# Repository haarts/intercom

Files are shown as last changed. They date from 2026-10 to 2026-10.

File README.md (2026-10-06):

# Intercom boerderij

A home intercom built from Waveshare ESP32-P4-WIFI6-POE-ETH wall boxes. There are two routes:

- **Mumble:** the boxes run a Mumble client. There is one Mumble server for the house,
  Mumble channels route audio to rooms, and Home Assistant is integrated.
- **lanicom** (`lanicom/`): serverless. Boxes find each other on the LAN and talk
  directly, with encrypted unicast. No Mumble server, and Home Assistant is optional (it can join as a
  peer), so friends can build it too. See [lanicom/README.md](lanicom/README.md) and the
  plan with its design review in [lanicom/PLAN.md](lanicom/PLAN.md).

| Path | What |
| --- | --- |
| `lanicom/` | Serverless intercom: protocol spec, C core, ESPHome component, Python CLI, HA integration |
| `esp32-mumble/` | [dchote/esp32-mumble](https://github.com/dchote/esp32-mumble) (git subtree) with ESP32-P4 support and audio fixes. Board config: `esp32-mumble/esphome/waveshare-esp32-p4-poe.yaml` |
| `esphome/p4-bringup.yaml` | Minimal bring-up config for the board (Ethernet, codec, mic level) |
| `server/mumble/` | Docker Compose file for the Mumble server (Murmur) |
| `tools/voicetest/` | End-to-end voice test: play speech near the board, record it from Mumble, score it with Whisper |
| `PROJECT_NOTES.md` | Decisions, measurements and open items |

## Build and flash

```sh
python3 -m venv .venv && .venv/bin/pip install esphome==2026.7.1
cd esp32-mumble/esphome
../../.venv/bin/esphome run waveshare-esp32-p4-poe.yaml   # first flash over USB-C, later OTA
```

The Mumble server address is filled in automatically with Home Assistant's IP when
the device is adopted, or set it under the device's "1. Server" setting.

## Voice test

```sh
tools/voicetest/run.sh local ptt tools/voicetest/berend-nl-pad.wav nl
```

Plays the clip on this machine's default audio output, records what the board sends
to the Mumble server, and prints Whisper's transcript and word error rate. See the
comments in `run.sh` for the options.

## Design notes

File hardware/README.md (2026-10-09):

# Intercom hardware

About ten wall boxes, each with a Waveshare ESP32-P4-ETH (sku ESP32-P4-POE-ETH, PoE module on top; no WiFi), a 40 × 40 mm speaker, four
illuminated push buttons (M19, Φ22 bezel, 3–6 V LED ring) and a 180 × 90 × 3 mm brass front
plate. The box sits on the in-wall box the UTP comes out of, with its back against the wall.

| Path | What | Status |
|---|---|---|
| `plate/front-plate-arches.dxf` | Front plate for the laser cutter | Holes corrected (below). Grille pattern still to check with the cutter. |
| `plate/front-plate-arches.scad` | The same plate for the enclosure model, generated by `plate/dxf2scad.py` | Regenerate after changing the DXF |
| `enclosure/intercom.scad` | Parametric OpenSCAD model of the 3D-printed prototype: shell, wall plate, mic tube | Carrier + ESP32-P4-ETH version, not printed yet |
| `carrier/` | KiCad project for the button/LED carrier board | Rev B in KiCad (adds the off switch J8): ERC clean, DRC 0 errors / 0 unconnected. `carrier/export/` still holds rev A, which is what was ordered. |

## GPIO map (P4-ETH header P1, Pico-style numbering)

Pin 1 is at the USB-C end of the left row, seen from the top with USB-C pointing up; pins 21–40 run back
up the right row, from the RJ45 end. Source: Waveshare's [ESP32-P4-ETH](https://docs.waveshare.com/ESP32-P4-ETH) pinout.

| Use | GPIO | P1 pin | Carrier socket |
|---|---|---|---|
| Button 1 (PTT) | GPIO23 | 31 | J7.11 |
| Button 2 | GPIO22 | 32 | J7.12 |
| Button 3 | GPIO21 | 34 | J7.14 |
| Button 4 | GPIO20 | 35 | J7.15 |
| LED ring 1 | GPIO5 | 11 | J1.11 |
| LED ring 2 | GPIO32 | 26 | J7.6 |
| LED ring 3 | GPIO4 | 12 | J1.12 |
| LED ring 4 | GPIO33 | 25 | J7.5 |
| Spare | GPIO2, GPIO3 | 15, 14 | J1.15, J1.14 → J6 |
| Off switch (`EN` = `3V3_EN`) | | 37 | J7.17 → J8 (rev B; a bodge on rev A, see below) |
| +5 V (VSYS) | | 39 | J7.19 |
| GND | | 3, 8, 13, 18, 23, 28, 33, 38 | |

## Carrier board (`carrier/`)

90 × 48 mm, two layers, through-hole only so it can be hand-soldered.

**The P4:**
- **Mounting:** it plugs in from above into two 1×20 female sockets (J1 = P1 pins 1–20, J7 = pins 21–40), 17.78 mm apart.
- **Orientation:** the silkscreen marks the RJ45 end and the USB-C end.
- **Under the P4:** only traces, so the P4's bottom-side parts are clear.
- **PoE module:** it stays on top of the P4 as usual; nothing on the carrier is near it.

**Per button** (four channels along the bottom edge, BTN1–BTN4 from left to right). The buttons are numbered in the order their GPIOs leave the header, so the four button lines run side by side without crossing:
- **Connector:** a JST-XH 4-pin. Pin 1 = LED+ (+5 V), 2 = LED−, 3 = switch, 4 = GND.
- **Switch input:** 1 kΩ in series to the GPIO, with 100 nF to GND. The pull-up is the ESP32's own; a pressed button reads low.
- **LED ring:**
  - switched low-side by a BC547, with a 1 kΩ base resistor and a 10 kΩ base pull-down that keeps it off during boot;
  - a series resistor (R13–R16) is fitted with 0 Ω until a ring's current at 5 V has been measured.

**Also on the board:**
- 10 µF on 5 V (C5).
- J6, a 1×4 header for the spares: GPIO2, GPIO3, GND, GND. It is at the USB-C end, so don't use it while a USB cable is plugged in.
- J8 (rev B), a JST-XH 2-pin for the off switch: 1 = `3V3_EN` (P1 pin 37), 2 = GND, with C6 (100 nF) across it.
  It is in the bottom-right corner, in line with the button JSTs; J5 moved 1 mm to the left to make room.
- GND pours on both layers.
- Four M3 holes (H1–H4).

ESPHome: buttons `INPUT_PULLUP`, `inverted: true`; LEDs as `ledc` outputs (dimming, pulsing).

### Off switch

Rev B has it on J8 (above). The notes below apply to both revisions; the wiring is the rev A bodge.

A toggle switch between J7.17 (P1 pin 37) and J7.18 (pin 38, GND) turns the box off. Closed = off.
Both socket pins are free on rev A and sit next to each other, so it is two wires on the carrier and nothing on the P4.

From Waveshare's [schematic](https://files.waveshare.com/wiki/ESP32-P4-ETH/ESP32-P4-ETH-datasheet.pdf):
- **What pin 37 is:** `EN` on the header is `3V3_EN`, the enable of the MP1658 buck (U1) that makes `ESP_3V3` from 5 V.
  It is pulled up to 5 V with 10 kΩ (R21). Pulling it low removes 3.3 V from the P4, so the switch is a real power-off,
  not a reset or sleep, and firmware can't override it.
- **Pin 30 is a different pin:** `RUN` is `ESP_EN` (the RESET button). Holding it low keeps the chip in reset with everything still powered.
- **What stays powered while off:**
  - the PoE module;
  - the analog 3.3 V LDO (U8, always enabled) for the codec and mic;
  - the power LED.
- **What goes dark by itself:**
  - the speaker amp (NS4150B, CTRL = GPIO53 with a 10 kΩ pull-down);
  - the LED rings (base pull-downs).
- **Wiring:** keep the wires inside the box and twisted. A 100 nF cap across the switch is cheap insurance against noise on EN.
- **Switching back on** is a cold boot. Partners see the box as offline after 30 s, because no `bye` is sent.
- **Factory reset still works:** ESPHome counts power-on resets, so flicking the switch 5 times within 10 s
  does a factory reset, like 5 power cycles. That is intended: the switch is a handy reset gesture.
- **To check on the first board:**
  - with the switch off, `ESP_3V3` (pin 36) should read ~0 V. If it floats at 1–2 V, something is back-powering the P4 through its IO pins;
  - measure the power draw while off.

## Front plate

`plate/front-plate-arches.dxf` is a copy of `intercom-grill-arches.dxf` (2026-09-30) with two fixes:

- **Button holes:** Ø16 → **Ø19.4**, for the M19 switches.
- **Mounting holes:** Ø3.0 → **Ø3.3**, for M3.

The countersink note (layer `INFO_CSK`, Ø6) is unchanged.

Still open:
- the grille's minimum slot and web width, to agree with the laser cutter;
- the switches' thread length and nut size;
- each bezel's top edge touches the bottom of the grille (y = 25 mm). Check that this looks right.

## Enclosure prototype (3D print)

```
enclosure/render.sh        # needs an OpenSCAD development snapshot (2025 or later): `openscad-nightly`,
                           # `openscad`, or OPENSCAD=/path/to/OpenSCAD.AppImage
```

The model is one file, `enclosure/intercom.scad`. Every dimension a test print may change is a
parameter at its top. Open it in OpenSCAD to look around: `part` selects what is shown
(`assembly`, `shell`, `wall_plate`, `mic_tube`, `section`).

It is designed in front-view coordinates (X right, Y up, Z into the wall), the way the plate
drawing and KiCad's top view read. Every output is mirrored once into the right-handed frame
that slicers use; without that, the print would be a mirror image of the box.

`render.sh` writes to `enclosure/out/`:
- `shell`, `wall_plate` and `mic_tube`, each as `.stl` and `.3mf` (the plate is brass, so it's never in them);
- preview PNGs: front, back, iso, inside, inside_iso and a section through the carrier;
- a collision check between the shell, the plate, the electronics, the speaker, the buttons
  and the mic tube, with the electronics, speaker and buttons as blocks. It fails if any two
  of them overlap (faces that merely touch are fine);
- how much of the mic tube's bore is covered by brass where it meets the plate (should be 0 %).

The plate in the model is the real one: OpenSCAD can't read the DXF's R12 polylines, so
`plate/dxf2scad.py` converts it (`python3 dxf2scad.py front-plate-arches.dxf > front-plate-arches.scad`).

**Shell, 185.4 × 95.4 × 52 mm:**
- **Plate:** sits in a rebate, flush with the front, and is screwed to four corner bosses with M3 heat-set inserts.
- **Inside, from the left:**
  - the speaker in a closed chamber, which improves the low end; a ledge holds it against the plate;
  - the cable opening, right next to the P4's RJ45 jack;
  - the carrier on four 5 mm standoffs (M3 inserts) on the back wall, above the buttons, components towards the plate.
- **The stack, from the back wall:**
  - carrier (component side at 42.4 mm behind the front);
  - 8.5 mm sockets;
  - the ESP32-P4-ETH (component side at 32.3 mm);
  - the RJ45 and the PoE module, which stick out about 13 mm towards the plate.

  That leaves about 16 mm free behind the plate.
- **Buttons:** the JSTs are on the carrier's bottom edge, a short cable away from them.
- **Bottom:** vent slots under the carrier. Warm air leaves through the grille.
- **USB-C:** it points at the right side wall with only 9 mm to spare. Flash the P4 before you mount it; after that, update it over the network (OTA).

**Wall plate, 174 × 85 × 3 mm:**
- **Mounting:** it screws onto the in-wall box.
  - Slots fit 60 mm screw spacing, horizontal or vertical, around `WALLBOX_CENTER` (behind the cable opening by default).
  - The shell's back has recesses for the screw heads.
- **Fixing the shell:** hang the shell on the two top hooks (above the carrier) and slide it 5 mm down. Two M3 screws from below go into the wall plate's tabs.

**Print settings:** PETG (or ASA near a heat source), 0.2 mm layers, 4 perimeters around the inserts.
Print the shell with its back on the bed; the rebate and bosses need no supports.

**Hardware per box:**
- 4× M3 heat-set inserts + M3×8 countersunk screws for the plate;
- 4× M3 inserts + M3×6 screws for the carrier;
- 2× M3 inserts + M3×16 screws to fix the shell to the wall plate;
- 2 screws for the wall box (usually supplied with it).

### To verify with the first print
- **Mic:** it is on the P4, next to the USB-C, 29 mm behind the plate (`MIC_XY` in the script), and will sound muffled without help.
  It is top-port (a hole in its lid, near the end towards the USB-C), so it hears towards the plate.
  - `mic_tube.stl` runs from the plate to 3.6 mm in front of the mic, clear of the USB-C. Glue its flange behind the plate and close the last gap with a foam ring.
  - It starts behind a grille opening (`MIC_GRILLE_XY`, the bore fully open) and slants about 7° to the mic.
  - Its 3 mm bore is centred on the lid's hole, whose position is estimated (~0.8 mm from the mic's
    USB-C end). Check it against the board before gluing; `MIC_XY` moves it.
- **PoE module:** modelled as a 32 × 26 × 13 mm block. Check the real height and overhang.
- **Cable:** the RJ45 plug and the cable's bend between the jack and the cable opening. A slim patch cable helps.
- **Speaker chamber:** the wires leave through a 4 × 3 mm notch where the chamber's right wall meets the back wall.
  Seal it with hot glue after fitting, check the chamber is airtight, and add foam between the speaker and the plate.
- **Button depth:** 46 mm inside depth assumes a 33 mm body plus its plug. Measure the real buttons.
- **Button cables:** the JSTs are labelled BTN1–BTN4 from left to right; cut each cable to its button.

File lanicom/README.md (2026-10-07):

# lanicom: serverless LAN intercom

Push-to-talk intercom devices that find each other on the LAN and talk
directly. No Mumble server, and Home Assistant is optional (it can join as a
peer). Every packet is encrypted and authenticated with a shared network key.

- Why it's built this way, the status and the latency budget: [PLAN.md](PLAN.md)
- The wire protocol: [spec/PROTOCOL.md](spec/PROTOCOL.md)
- Setting up devices (for friends): [docs/friends.md](docs/friends.md)
- Buttons, pairing and LED patterns: [docs/buttons.md](docs/buttons.md)

| Path | What |
|---|---|
| `spec/` | Protocol, protobuf schema, shared test vectors |
| `lanicom-core/` | Portable C protocol engine (used by the firmware), with host tests |
| `esphome/` | ESPHome component and the Waveshare ESP32-P4 board config |
| `python/` | Reference implementation and the `lanicom` command-line peer |
| `ha/` | Home Assistant integration |

## Try it on two computers

```sh
pip install -e 'lanicom/python[audio]'   # needs libopus0 and PortAudio (Debian: apt install libopus0 libportaudio2)
lanicom keygen --save                    # once; copy ~/.config/lanicom/key to the other machine
lanicom list                             # who is on the network
lanicom talk --to all                    # Enter starts/stops talking; also plays what others say
lanicom send doorbell.mp3 --to all       # play a file (needs ffmpeg)
lanicom record out.wav --duration 10     # record what others say
```

## Tests

```sh
cmake -S lanicom/lanicom-core -B lanicom/lanicom-core/build && cmake --build lanicom/lanicom-core/build \
  && ctest --test-dir lanicom/lanicom-core/build          # C core (needs libmbedtls-dev), ASan/UBSan
pip install -e 'lanicom/python[test]' && pytest lanicom/python   # Python + C interop (after the C build)
cd lanicom/ha && pytest                                   # HA (pip install pytest-homeassistant-custom-component ha-ffmpeg)
```

After changing the protocol, regenerate the vectors (`python lanicom/python/tools/gen_vectors.py`)
and the integration's copy of the library (`python lanicom/ha/sync_lib.py`).

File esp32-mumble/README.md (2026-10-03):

# ESP32-Mumble

An ESP32-S3 Mumble voice chat client for ESPHome, turning microcontroller boards into always-on intercoms and push-to-talk devices.

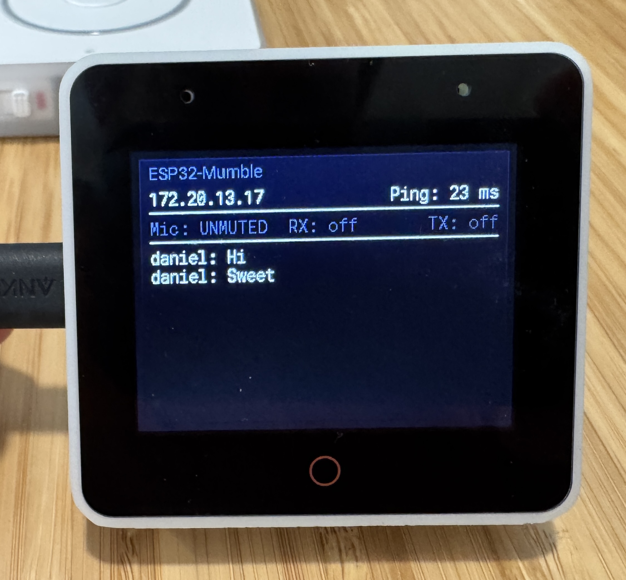
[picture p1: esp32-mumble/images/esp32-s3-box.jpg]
ESP32-S3-BOX running ESP32-Mumble


*The project running on an ESP32-S3-BOX connected to a local go-mumble-server instance.*

## What Is This?

ESP32-Mumble implements the [Mumble](https://www.mumble.info/) voice chat protocol on ESP32-S3 hardware. **Default crypto is Legacy** (OCB2-AES128, standard Mumble); **Lite** (cleartext UDP, minimal CPU) is optional for trusted LAN. Connects to [go-mumble-server](https://github.com/dchote/go-mumble-server) or Murmur.

The firmware runs as an [ESPHome](https://esphome.io/) external component, integrating with Home Assistant for configuration and control.

### Key Capabilities

- **Three operating modes**: Always-on intercom, push-to-talk, and **Communicator** (Star Trek-style half-duplex)
- **Crypto modes**: **Legacy** (default) — OCB2-AES128; **Lite** — cleartext UDP for trusted LAN; **Secure** — AES-256-GCM when server negotiates it (go-mumble-server)
- **Opus** audio encoding/decoding at 16 kHz
- **Microphone capture and transmit** (Opus encode, VAD, echo suppression)
- **Acoustic echo cancellation** for open-mic use
- **Home Assistant** entities for server config, mode, mute, volume, channel, and status
- **Multi-room** intercom via Mumble channels

---

### Communicator Mode

Communicator mode turns any supported board into a **Star Trek-style half-duplex intercom**. A single button press opens a communication session with an audible chime, transmits your voice, and automatically closes when you stop talking.

**How it works:**

1. **Press the button** — an open chime plays, then the microphone goes live
2. **Speak** — audio is transmitted via Mumble with VAD (voice activity detection); silence is not sent
3. **Stop speaking** — after 2 seconds of silence the session auto-closes with a close chime
4. **Press again during a session** — immediately cancels and plays the close chime

While a communicator session is active, incoming voice is suppressed so the bus stays on the microphone. The chime is embedded directly in the firmware as raw PCM and played through the component's own bus-aware speaker path — no media player needed.

Communicator mode is selectable from the **Mode** entity in Home Assistant (alongside Always On and Push to Talk) and persists across reboots. On boards with a physical button (Box, Box-3, Atom Echo, Voice PE), the same button handles all three modes automatically.

---

## Supported Hardware

| Board | Framework | Mic | Speaker | Highlights |
|---|---|---|---|---|
| ESP32-S3 Box | ESP-IDF | ES7210 mic array | ES8311 DAC | lwIP netconn UDP |
| ESP32-S3 Box 3 | ESP-IDF | ES7210 mic array | ES8311 DAC | Same as Box; pin differences |
| Home Assistant Voice PE | ESP-IDF | XMOS dual mic | AIC3204 DAC | Jog volume, mute slider, center PTT, LED ring |
| Onju Voice | Arduino | SPH0645 I2S | MAX98357A I2S | Nest Mini form factor, touch, LEDs |
| M5Stack Atom Echo | Arduino | PDM mic | External DAC | Compact |
| Generic ESP32-S3 | Arduino | Any I2S mic | Any I2S DAC/amp | User-defined pins |
| Waveshare ESP32-P4-WIFI6-POE-ETH | ESP-IDF | Analog mic via ES8311 | ES8311 DAC | ESP32-P4 (rev3), Ethernet/PoE, native esp-idf toolchain |

The ESP32-S3 boards require PSRAM and Wi-Fi. The ESP32-P4 board connects over Ethernet and
builds with ESPHome's native esp-idf toolchain (see `esphome/waveshare-esp32-p4-poe.yaml`).

## Architecture

```
ESP32-S3                              go-mumble-server
┌────────────────────┐               ┌──────────────────┐
│ ESPHome Component  │──TCP/TLS────►│  Control (64738)  │
│                    │               │                   │
│ Mic/Opus encode    │               │  Voice  (64738)   │
│ Opus Dec ► I2S Spk │◄──UDP voice (rx/tx)────│
│                    │               └──────────────────┘
│ HA Entities ◄─────►│ Home Assistant
└────────────────────┘
```

See the full documentation:

- **[Product Overview](docs/product-overview.md)** -- Vision, use cases, features, and target hardware
- **[Technical Overview](docs/technical-overview.md)** -- Protocol details, audio pipeline, ESPHome integration, and hardware abstraction

## Prerequisites

- A Mumble server (e.g. [go-mumble-server](https://github.com/dchote/go-mumble-server) or Murmur) on your LAN
- [ESPHome](https://esphome.io/) 2026.7.0+ (pin via `pip install -r requirements.txt` → 2026.7.1)
- Python 3.12+
- [Home Assistant](https://www.home-assistant.io/) (optional, for configuration and control UI)
- One of the supported ESP32-S3 boards listed above

## Quick Start

```bash
# Clone, set Wi‑Fi in esphome/secrets.yaml; server defaults to empty and is auto-filled from HA when adopted
esphome compile esphome/esp32-s3-box.yaml   # Box: ESP-IDF; or generic-esp32s3.yaml for Arduino
esphome run esphome/esp32-s3-box.yaml --device /dev/ttyUSB0
```

For Box/Box-3 (ESP-IDF): first flash must be via USB, not OTA.

See [docs/build.md](docs/build.md) for full build and flash instructions.

## OTA Updates & Releases

Pre-built firmware is published from SemVer tags (`vX.Y.Z`) via GitHub Actions:

| Channel | URL |
|---|-----|
| Web installer (USB / ESP Web Tools) | https://dchote.github.io/esp32-mumble/ |
| Per-board OTA manifests | `https://dchote.github.io/esp32-mumble/<board>/manifest.json` |
| GitHub Release assets | https://github.com/dchote/esp32-mumble/releases |

Board slugs: `esp32-s3-box`, `esp32-s3-box3`, `home-assistant-voice-pe`, `m5stack-atom-echo`, `generic-esp32s3`.

After a device is adopted in Home Assistant, the **Firmware Update** entity checks the board's GitHub Pages manifest (every 6 hours) and can install OTA updates. Manifests and `.ota.bin` files are hosted on Pages (not `releases/latest/download`) to avoid GitHub redirect URL length limits on the device HTTP client.

**One-time maintainer setup:** enable GitHub Pages for this repo with **Source = GitHub Actions** (Settings → Pages). See [docs/features/0015-ota-releases.md](docs/features/0015-ota-releases.md).

**Cut a release:**

```bash
git tag v1.0.0
git push origin v1.0.0
```

Configure Mumble server, port, username, password, channel, mode, and crypto from the Home Assistant UI after adding the device. **Server** defaults to empty and is auto-populated with the Home Assistant server IP when the device is adopted by HA (e.g. for the go-mumble-server addon); set it manually in YAML or HA to override. **Crypto** defaults to Legacy (OCB2-AES128). Values persist in NVS and are restored on boot. Username defaults to `esp32-<MAC>`; you can overwrite it. Changing server, username, password, channel, or crypto forces a reconnect. **Mode** selects between Always On, Push to Talk, and Communicator — switching modes takes effect immediately (mic is disabled when leaving always-on). Use **Speaker Volume** to adjust playback level. On Box/Box-3, **Speaker Power** controls the hardware amplifier. Diagnostics show connection status, ping, and voice activity. The **Reset Config** button restores all settings to defaults (server to empty, re-triggering HA auto-detection). See `esphome/generic-esp32s3.yaml` for the full pattern.

## Project Structure

```
esp32-mumble/
├── components/          # ESPHome external components
│   └── mumble/          # Mumble client component
├── lib/
│   └── micro-opus/      # Local Opus codec (v0.4.1; heap pseudostack, PSRAM, Xtensa)
├── scripts/
│   ├── build.sh
│   ├── flash.sh
│   ├── generate_communicator_chime.py
│   └── patch_mbedtls_requires.py
├── docs/
│   ├── build.md
│   ├── features/        # Including 0015-ota-releases.md
│   ├── product-overview.md
│   └── technical-overview.md
├── esphome/             # Example device configs + secrets.example.yaml
├── .github/workflows/   # build.yml (PR/main) + release.yml (tags → Pages/Releases)
├── requirements.txt     # Pins esphome==2026.7.1
├── SECURITY.md
├── README.md
└── LICENSE
```

Install the host toolchain with `pip install -r requirements.txt`. See [docs/build.md](docs/build.md) and [SECURITY.md](SECURITY.md).

## Contributing

This project is in early development. Contributions, ideas, and hardware testing are welcome. Please open an issue to discuss before submitting large changes. Run `pre-commit run --all-files` before opening a PR.

## License

[MIT](LICENSE)

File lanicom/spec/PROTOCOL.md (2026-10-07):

# lanicom protocol, version 1

Normative. The key words MUST, SHOULD and MAY are as in RFC 2119. Test vectors
are in [`vectors/`](vectors/); every implementation MUST pass them.

lanicom is a serverless push-to-talk intercom for one LAN. Every device is an
equal peer. Devices find each other with authenticated broadcast `Hello`
messages and send audio directly to each other over UDP.

## 1. Transport

- All traffic uses UDP port **47100** (configurable; every device in a network
  MUST use the same port). One socket sends and receives both packet types.
- Discovery uses the IPv4 limited broadcast address `255.255.255.255`.
- Optional multicast (section 8) uses group `239.255.76.73` on the same port.
- A packet MUST NOT exceed 1200 bytes. Receivers drop larger datagrams.
- IPv6 is out of scope for v1.

## 2. Keys

Every device in a network shares one **key string**, normally generated by
`lanicom keygen` (25 random base32 characters in five dash-separated groups,
125 bits). Any passphrase works, but a weak one can be brute-forced offline
from one captured packet, despite the PBKDF2 stretching.

Leading and trailing whitespace is stripped. Everything else, including case and
dashes, is significant.

```
master   = PBKDF2-HMAC-SHA256(password = UTF-8(key string),
                              salt = "lanicom-v1", iterations = 100000, dkLen = 32)
prk      = HKDF-Extract-SHA256(salt = "lanicom-v1", ikm = master)
key_id   = uint16_be(HKDF-Expand-SHA256(prk, info = "key-id", L = 2))
send_key(sender_id) = HKDF-Expand-SHA256(prk, info = "packet" || uint32_be(sender_id), L = 32)
```

- `key_id` is public. Receivers use it to drop traffic from other networks
  cheaply before attempting decryption. It also allows a future key rotation in
  which two keys are accepted at once.
- Each sender has its own AEAD key. Two devices that happen to pick the same
  epoch therefore never reuse a (key, nonce) pair.

## 3. Packet format

All integers are big-endian.

| Offset | Size | Field | Notes |
|---|---|---|---|
| 0 | 1 | `version` | `1` |
| 1 | 1 | `type` | `1` = CONTROL, `2` = AUDIO |
| 2 | 2 | `key_id` | from section 2 |
| 4 | 4 | `sender_id` | random at first boot, then persisted; never `0` |
| 8 | 8 | `epoch` | unique per sender per boot (see below) |
| 16 | 4 | `seq` | per sender, +1 for every packet sealed in this epoch, starts at 0 |
| 20 | n | ciphertext | |
| 20+n | 16 | Poly1305 tag | |

Packets are sealed with ChaCha20-Poly1305 (RFC 8439), using:

- `key` = `send_key(sender_id)`;
- `nonce` = bytes 8..19 of the header (`epoch || seq`, 12 bytes);
- `aad` = the 20-byte header.

The (key, nonce) pair MUST never repeat, which leads to these rules:

- `seq` is a single counter per sender. It is shared by both packet types and
  by all destinations.
- When a sender sends the same packet to several peers, it seals it **once** and
  sends identical bytes to each peer. This is allowed and is cheaper.
- `epoch` MUST NOT repeat for a given sender. RECOMMENDED: `uint32 boot_counter`
  (persisted and incremented before the first packet of a boot) `||` `uint32
  random`. Hosts without persistent storage use 64 random bits. Before `seq`
  would wrap, the sender MUST pick a new epoch.

### Receive procedure

A receiver processes each datagram in this order, stopping at the first
failing step. Every drop is counted per reason, and none produces a reply
except where noted:

1. The length is at least 36 and at most 1200, `version == 1`, and
   `type` is known. Otherwise drop (`malformed`).
2. `key_id` equals ours. Otherwise drop (`foreign`).
3. `sender_id` is not our own. If it is and `epoch` equals ours, this is our
   own broadcast looping back: drop it silently. If it is with a different
   epoch, another device has the same id: drop it, and if the packet also
   authenticates, pick a new random `sender_id`.
4. Open with `send_key(sender_id)`. If this fails, drop (`auth`).
5. Epoch verification (section 4). Packets from an unverified epoch are only
   used as described there.
6. Replay check against the sender's verified epoch (section 4). Duplicates
   and too-old packets are dropped (`replay`).
7. Update the peer's address (source IP and port) and `last_seen`, then
   dispatch on `type`.

## 4. Epoch verification and replay protection

An attacker on the LAN can record packets and send them again later. A
per-epoch sliding window (64 packets) catches replays within one epoch.
Without further checks, though, a receiver that never saw an epoch, or that
rebooted since, would accept a whole recorded session. Epoch verification
closes that gap with a challenge that needs no clock:

- Each peer entry has a `verified_epoch` (initially none).
- When an authenticated packet arrives from an epoch other than
  `verified_epoch`, the receiver does this:
  - **Hello with `echo` equal to the challenge pending for that peer:** set
    `verified_epoch` to the packet's epoch, start a fresh replay window at its
    `seq`, clear the challenge, and process the Hello normally.
  - **Anything else:** send that peer (at the packet's source address) a
    unicast Hello with a fresh random non-zero 64-bit `challenge`, at most once
    per 250 ms per peer. Create the peer entry if it is new. Then drop the
    packet, except that a Hello's own `challenge` field (if any) is still
    answered, as below. Nothing else changes.
- A Hello carrying `challenge = c` is always answered with a unicast Hello
  whose `echo = c`, sent from the current epoch, even if the challenger is not
  verified yet. Replies are limited to 10 per second per source address.
- The replay window keeps the highest `seq` seen and a 64-bit bitmap of the
  64 `seq` values below it. A packet more than 63 behind the highest is
  dropped as too old. A packet whose bit is already set is dropped as a
  duplicate.

Two peers meeting for the first time thus verify each other within two round
trips, in practice when the first `Hello` is seen and long before anyone
talks. A rebooted sender's first audio frames arrive before peers have
verified its new epoch only if it talks within about 1 ms of booting.

**Residual risks (accepted for v1):**
- Every holder of the network key can impersonate any `sender_id`. There are no
  per-device identities; this is a non-goal.
- `key_id`, sender ids, epochs, packet sizes and timing are visible, so traffic
  analysis can tell who is talking to whom.

## 5. Control messages

The CONTROL plaintext is one protobuf `Control` message, as defined in
[`lanicom.proto`](lanicom.proto). Unknown fields MUST be skipped.

### Discovery and liveness

- A device sends a `Hello` (with no `challenge` or `echo`) to the broadcast
  address at start-up, three times (at 0, 0.5 and 1.5 s). After that it sends
  one every 5 s, with ±1 s random jitter.
- It also sends `Hello` to any statically configured peer addresses on the same
  schedule. This is for networks where broadcast doesn't reach, such as across
  routed VLANs.
- A peer is forgotten after 30 s without a verified packet, or immediately on
  a verified `Hello` with `bye = true`.
- `name` is a display name (UTF-8, ≤ 32 bytes). A changed name takes effect
  with the next `Hello`.
- `caps`: bit 0 `PLAYBACK` (plays audio), bit 1 `CAPTURE` (can talk), bit 2 `MONITOR`
  (wants talk metadata for every stream, e.g. Home Assistant, without receiving audio),
  bit 3 `ANNOUNCER` (v1.1: may talk to any device, see section 7).
- `links` (v1.1): the sender's linked buttons, see section 7.

### Talk metadata

- `TalkStart {target, stream_id}` is sent just before each of a stream's first
  three audio packets, and `TalkStop {stream_id}` three times after its last
  one. Both go by unicast to every recipient of the stream and to every
  verified peer with `MONITOR` set, whatever the target. They are never sent
  by multicast.
- These are **informational** (for UI, LEDs and Home Assistant events). Playback
  MUST NOT depend on them: a stream starts with its first audio packet and ends
  after 300 ms without audio, or on `TalkStop`.
- Receivers dedupe both on (sender_id, stream_id).

## 6. Audio

The AUDIO plaintext is:

| Offset | Size | Field |
|---|---|---|
| 0 | 4 | `stream_id`, random per talk spurt (never 0) |
| 4 | 4 | `ts`: timestamp of the first sample, in 48 kHz ticks, random start, +480 per 10 ms |
| 8 | n | exactly one Opus packet (n ≥ 1) |

- **Codec:** Opus, mono. Senders SHOULD encode at 16 kHz in VOIP mode with
  in-band FEC enabled, 10 ms frames (20 ms is allowed, for example to halve the
  packet rate on Wi-Fi), at 16 to 24 kbit/s.
- Receivers MUST accept 10, 20, 40 and 60 ms frames. They get the frame length
  from the Opus packet itself.
- The jitter buffer orders frames by `ts`. It MUST NOT use the header `seq`:
  that counter also advances for packets sent to other peers, so gaps in it say
  nothing about loss.
- On a missing frame, the receiver decodes the next frame's in-band FEC if that
  frame is already buffered, and uses Opus PLC otherwise.
- Concurrent streams are mixed (summed with saturation). There is no floor
  control.

### Addressing

A talker resolves its `Target` against its peer table at send time:

- `device`: that peer.
- `all`: every peer.

To reach a set of devices, a talker sends one stream to all of them, and each of
them gets its own `TalkStart` naming it (`device`). Devices can join or leave a
running stream: a joining device gets its three `TalkStart`s, a leaving one its
three `TalkStop`s.

A talker only includes peers that have `PLAYBACK` set and are verified. It seals
each frame once and sends a copy to every peer in the set (unicast fan-out).

## 7. Buttons and pairing (v1.1)

Devices with buttons (wall boxes) talk only through their buttons. Each button
is **linked** to exactly one button on another device, its partner. Holding a
button talks to its partner; holding several talks to all their partners in one
stream (section 6, Addressing). Buttons are numbered from 1.

### Pairing

1. Holding an unlinked button for 5 s puts it in **pairing mode** for 60 s. A
   linked button never enters pairing mode (a long hold is a long talk). A short
   press ends pairing mode.
2. In pairing mode the device broadcasts `PairOffer {nonce, button}` once a
   second. `nonce` is random, non-zero, new for each pairing mode.
3. Every device remembers the offers it hears (sender, nonce, button) until
   none has arrived for 2.5 s.
4. When a button enters pairing mode and an offer is known that none of the
   device's own buttons is already answering, it answers the oldest one (first
   heard) instead of offering: `PairAccept {nonce, button}` by unicast to the
   offerer, `button` being its own. It repeats the Accept every 500 ms until it
   gets a `PairConfirm`, for up to 5 s; then it forgets that offer and offers
   itself.
5. If two buttons offer at the same time, the one with the larger nonce accepts
   the other's offer (unsigned comparison), so exactly one side accepts.
6. The offerer, on a `PairAccept` whose nonce matches a button in pairing mode
   that isn't itself accepting, sends `PairConfirm {nonce}` by unicast and saves
   the link (its button, the sender, the sender's button). A repeated Accept for
   a link it already made with that nonce gets another Confirm, nothing else.
7. The accepter saves the link when the matching Confirm arrives.

Pairing messages are ordinary CONTROL traffic, so only holders of the network
key take part. The 5 s holds on both devices are the user's confirmation.

### Links heal themselves

Every `Hello` lists the sender's links (`Hello.links`). When a device hears a
verified `Hello` from a partner, it checks each of its links to that partner
that is older than 15 s. If the Hello doesn't list the reverse link (the
partner's button, our sender_id, our button), the partner has dropped it, and
the device drops its side too. Unpairing or resetting a device thus clears its
partners' buttons with its next Hello; a partner that was offline catches up
when both are back. There is no unlink message.

A device announces a change of links at once, with a broadcast `Hello`.

### Who plays what

A device with buttons plays audio only from its buttons' partners and from
peers with `ANNOUNCER` set (Home Assistant). It drops other streams. Anyone with
the network key can claim `ANNOUNCER`.

Devices that predate v1.1 skip the new fields and messages, and a device
without buttons plays everything, as in v1.

## 8. Multicast (optional)

A device MAY enable multicast. It then joins `239.255.76.73` and sends frames
for target `all` to the group once, instead of fanning out. Devices that don't
enable multicast never receive multicast audio. A network should therefore
either enable it on every device or on none.

Multicast is meant for wired-only installs. On Wi-Fi, multicast is sent at the
lowest basic rate without retries, and many access points drop or rate-limit
it, so stay with unicast there.

## 9. Constants

| Name | Value |
|---|---|
| port | 47100 |
| multicast group | 239.255.76.73 |
| max packet | 1200 bytes |
| PBKDF2 iterations | 100000 |
| Hello interval | 5 s ± 1 s |
| peer timeout | 30 s |
| challenge rate limit | 1 / 250 ms / peer |
| echo rate limit | 10 / s / source |
| replay window | 64 |
| stream timeout | 300 ms |
| pairing hold | 5 s |
| pairing mode | 60 s |
| PairOffer interval | 1 s |
| offer forgotten after | 2.5 s |
| PairAccept retry | every 500 ms, for 5 s |
| link grace (no heal check) | 15 s |

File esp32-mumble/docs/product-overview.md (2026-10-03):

# Product Overview

## Vision

ESP32-Mumble is an always-on intercom and push-to-talk voice client that runs on ESP32-S3 microcontrollers. It implements the Mumble voice chat protocol, connects to [go-mumble-server](https://github.com/dchote/go-mumble-server), and integrates with Home Assistant through ESPHome.

The project targets LAN deployments. **Legacy mode** (OCB2-AES128 UDP encryption, standard Mumble protocol) is the default and works with any Mumble server (Murmur, go-mumble-server). **Lite mode** (cleartext UDP) is available for trusted LAN use when the server supports it.

## Use Cases

### Always-On Intercom

The device listens and transmits continuously, acting as a room intercom. Audio from the microphone streams to the Mumble channel in real time. A physical mute button (or HA-controlled software mute) silences the microphone without disconnecting. This is the default operating mode.

### Microphone Control

Transmitting is controlled by a physical button wired to `mumble.microphone_enable` / `mumble.microphone_disable` (press = on, release = off). In push-to-talk mode this provides hold-to-talk; in always-on mode it toggles. On Box/Box-3, the touch-screen red circle below the display acts as the PTT button. The `mumble.ptt_press` action toggles mic state for single-press buttons.

### Star Trek Communicator Mode

In **communicator** mode, a single button press opens a half-duplex session:

1. An **open chime** plays through the speaker (bus-aware, embedded PCM)
2. The microphone goes live — VAD detects speech and transmits via Opus
3. When you stop talking, a **2-second silence window** starts; if you resume speaking, the timer resets
4. After 2 seconds of continuous silence the session auto-closes with a **close chime**
5. Pressing the button again during an active session **cancels immediately** and plays the close chime

Incoming voice is suppressed while a communicator session is active so the I2S bus stays on the microphone. The chime audio is embedded in the firmware as raw 16-bit PCM (generated from `esphome/sounds/communicator.wav` by `scripts/generate_communicator_chime.py`) and played through the component's own speaker path — no ESPHome media player needed.

The state machine has five states: `IDLE` → `OPEN_CHIME` → `MIC_ACTIVE` → `SILENCE_WINDOW` → `CLOSE_CHIME` → `IDLE`. Mode switching from Home Assistant takes effect immediately and cancels any active session.

### Multi-Room Intercom

Multiple ESP32-Mumble devices join the same Mumble server, each in an assigned channel or all in one shared channel. Rooms can be grouped or isolated by channel, with channel assignment configurable from Home Assistant.

### Home Assistant Integration

Each device appears in Home Assistant as an ESPHome node with configurable entities for server connection, operating mode (always-on / push-to-talk), mute state, volume, active channel, and talking status. Automations can mute devices on a schedule, switch channels in response to events, or trigger notifications when someone begins talking.

## Target Hardware

| Board | Framework | Microphone | Speaker/DAC | Notes |
|---|---|---|---|---|
| **ESP32-S3 Box 3** | ESP-IDF | ES7210 4-ch mic array | ES8311 DAC | lwIP netconn UDP; I2C codec control |
| **ESP32-S3 Box** | ESP-IDF | ES7210 4-ch mic array | ES8311 DAC | Older revision of Box 3 |
| **Home Assistant Voice PE** | ESP-IDF | XMOS dual-mic DSP | AIC3204 DAC | Jog wheel volume, mute slider, center PTT/Communicator, LED ring |
| **Onju Voice** | Arduino | SPH0645 I2S mic | MAX98357A I2S amp | Drop-in Google Nest Mini replacement; touch, LEDs, mute switch |
| **M5Stack Atom Echo** | Arduino | PDM microphone | External I2S DAC | Compact form factor |
| **Generic ESP32-S3** | Arduino | Any I2S microphone | Any I2S amplifier/DAC | User-defined pin configuration |

All targets require an ESP32-S3 with PSRAM and Wi-Fi. The S3's dual-core architecture is needed for simultaneous audio encode/decode and network I/O.

## Features

### Audio

- Opus decoding of received voice streams to speaker output — **implemented**
- Opus encoding of microphone input (16 kHz, mono, ~16 kbps) — **implemented**
- Half-duplex capture and playback (shared I2S bus; mic and speaker take turns)
- Echo suppression: transmit is suppressed while receiving or within 100 ms after
- Microphone array support with beamforming on boards with multi-channel ADCs (ES7210)

### Mumble Protocol

- **Legacy mode** (default): Standard Mumble protocol with OCB2-AES128 UDP encryption. Connects to Murmur, go-mumble-server, or any Mumble server.
- **Lite mode** (optional): Cleartext UDP voice, TLS control. Minimal CPU; use on trusted LAN when the server supports it (e.g. go-mumble-server with Lite enabled).
- Join a configured channel on connect
- Receive and transmit Opus voice packets (UDP when active; TCP tunnel fallback when UDP unreachable)
- Channel changes via `UserState` (e.g. from HA channel select)
- Respond to server pings to maintain connection
- UDP voice with TCP fallback (UDPTunnel) if UDP is unreachable

### Controls and Indicators

- Microphone on/off via physical button (`mumble.microphone_enable` / `mumble.microphone_disable`)
- Push-to-talk via physical button (press-and-hold)
- Volume control via touch surface, button, or Home Assistant
- LED status indication:
  - Connecting (slow pulse)
  - Connected/idle (steady)
  - Talking (active animation)
  - Muted (distinct color)
  - Error (red)

### Home Assistant Configuration

The following settings are exposed as Home Assistant entities and can be changed from the HA UI without reflashing the device. Values persist in NVS across reboots.

| Entity | Type | Description |
|---|---|---|
| Server | Text | Hostname or IP of the Mumble server. Defaults to empty; when the device is adopted by Home Assistant, it is auto-populated with the HA server IP (e.g. for go-mumble-server addon). Set manually to override. |
| Port | Text | Server port (default 64738, displays as integer) |
| Username | Text | Mumble username; defaults to `esp32-<MAC>` on first run (user can overwrite) |
| Password | Text | Server or user password; no default |
| Channel | Text | Channel to join on connect (default **Root**; case-insensitive match) |
| Mode | Select | **Always on**, **Push to talk**, or **Communicator** (persisted across reboots) |
| Crypto | Select | **Legacy** (OCB2-AES128, default) or **Lite** (cleartext UDP for trusted LAN) |
| Speaker Volume | Number | Playback volume level (0–100, default 80) |
| Speaker Power | Switch | Hardware amplifier power on/off (Box/Box-3 GPIO46; Voice PE GPIO47) |

All settings persist in NVS and are restored on boot — including speaker volume. Changing server, port, username, password, channel, or crypto forces an immediate reconnect.

### Home Assistant Diagnostics

| Entity | Type | Description |
|---|---|---|
| WiFi Signal | Sensor | WiFi RSSI in dBm |
| Mumble Connected | Binary Sensor | Whether connected to the Mumble server |
| Mumble Ping | Sensor | Round-trip ping time to server in ms |
| Voice Received | Binary Sensor | True while voice is being received and processed (Sensors) |
| Reset Config | Button | Restore server (to empty, re-triggering HA auto-detection), port, username, password, channel, mode, and crypto to defaults |

### Home Assistant Runtime Entities

| Entity | Type | Status | Description |
|---|---|---|---|
| Voice Sending | Binary Sensor | Implemented | True while the device is transmitting audio |
| Speaker Volume | Number | Implemented | Speaker volume level 0–100 (persists across reboots) |
| Speaker Power | Switch | Implemented | Hardware amplifier on/off (Box/Box-3, Voice PE; persists) |
| Mumble Connected | Binary Sensor | Implemented | Connection status (Diagnostics) |
| Voice Received | Binary Sensor | Implemented | True while receiving voice (Sensors) |
| Channel | Text | Implemented | Channel name to join (config) |
| Channel Select | Select | Optional | Server-populated channel list (`channel_select_id`) |

## Server Requirements

The client uses **Legacy** crypto by default; **Lite** is optional for trusted LAN.

**Legacy mode** (default):

- Any Mumble server (Murmur, go-mumble-server, etc.)
- Standard Mumble protocol with OCB2-AES128
- Opus codec enabled

**Lite mode** (optional):

- **go-mumble-server** or compatible with Lite crypto mode enabled
- Trusted LAN deployment
- TLS certificate (self-signed acceptable)

## Non-Goals (v1)

The following are explicitly out of scope for the initial version:

- Server administration from the device
- Client certificate / client-initiated Secure tier (server can negotiate Secure; client accepts it)
- CELT or Speex codec support
- Positional audio
- Multiple simultaneous server connections
- Audio recording or playback of stored media

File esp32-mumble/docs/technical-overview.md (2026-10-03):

# Technical Overview

## System Architecture

```
┌─────────────────────────────────────────────────────────────────────┐
│                        Trusted LAN                                  │
│                                                                     │
│  ┌──────────────────┐         ┌──────────────────────────────────┐  │
│  │  go-mumble-server│         │  ESP32-S3 Device                 │  │
│  │                  │◄───────►│                                  │  │
│  │  TCP/TLS :64738  │ Control │  ┌────────────┐  ┌───────────┐  │  │
│  │  (Version, Auth, │ Channel │  │ MumbleClient│  │ AudioPipe │  │  │
│  │   CryptSetup,    │         │  │ (TCP/TLS)  │  │ (I2S+Opus)│  │  │
│  │   Ping, Sync)    │         │  └─────┬──────┘  └─────┬─────┘  │  │
│  │                  │         │        │               │         │  │
│  │  UDP :64738      │◄───────►│  ┌─────┴───────────────┴─────┐  │  │
│  │  (Opus voice,    │  Voice  │  │  UDP Voice (Lite or Legacy) │  │  │
│  │   Lite/Legacy)   │  Packets│  │  Cleartext or OCB2-AES128   │  │  │
│  │                  │         │  └────────────────────────────┘  │  │
│  └──────────────────┘         │                                  │  │
│                               │  ┌─────────┐  ┌──────────────┐  │  │
│  ┌──────────────────┐         │  │ ESPHome │  │ Home         │  │  │
│  │  Home Assistant  │◄───────►│  │ API     │  │ Assistant    │  │  │
│  │                  │  Native │  │         │  │ Entities     │  │  │
│  │  Dashboard       │  API    │  └─────────┘  └──────────────┘  │  │
│  └──────────────────┘         └──────────────────────────────────┘  │
└─────────────────────────────────────────────────────────────────────┘
```

The ESP32-S3 device maintains two network connections:

1. **Mumble server** — TCP/TLS for control messages and UDP for voice packets (Lite: cleartext; Legacy: OCB2-AES128), both on port 64738. UDP voice works on Box/Box-3 (ESP-IDF netconn); TCP tunnel fallback when UDP unreachable.
2. **Home Assistant** -- ESPHome native API for entity state, configuration, and OTA updates.

## Mumble Protocol

### Connection Lifecycle

The server sends Version immediately after TLS handshake; the client responds with Version and Authenticate. CryptSetup is sent by the server *after* authentication as part of sync:

```
ESP32                                         go-mumble-server
  │                                                 │
  │──── TCP connect + TLS handshake ───────────────►│
  │                                                 │
  │◄─── Version (CryptoModes=0x07) ─────────────────│  Server sends first
  │──── Version (CryptoModes=0x01 or 0x02) ────────►│  Lite only or Legacy only (per user selection)
  │──── Authenticate (user, pass, opus=true) ──────►│
  │                                                 │
  │◄─── CryptSetup (key=empty or 16 bytes) ─────────│  After auth, signals mode
  │◄─── ChannelState[] ────────────────────────────│
  │◄─── UserState[] ──────────────────────────────│
  │◄─── ServerConfig ─────────────────────────────│
  │◄─── CodecVersion (opus=true) ──────────────────│
  │◄─── ServerSync (session, welcome) ─────────────│
  │                                                 │
  │──── UDP Ping ──────────────────────────────────►│
  │◄─── UDP Ping echo ────────────────────────────│
  │                                                 │
  │◄──► UDP Voice (Opus, Lite or Legacy) ◄────────►│
  │◄──► TCP Ping (keepalive) ◄────────────────────►│
```

**Channel selection** — The client joins the channel specified in the Channel text entity. Changing the channel in HA forces a reconnect; the new channel name is matched case-insensitively (e.g. `root` matches `Root`).

### Crypto Modes

go-mumble-server negotiates security per client during the Version exchange. The ESP32 client advertises supported modes; the server selects the best mutual tier. **Default crypto mode is Legacy** (OCB2-AES128).

| Mode | CryptoModes bit | UDP treatment | Use case |
|---|---|---|---|
| **Legacy** | 0x02 | OCB2-AES128, 4-byte overhead | Standard Mumble (Murmur, go-mumble-server); **default** |
| **Lite** | 0x01 | Cleartext, no per-packet crypto | Trusted LAN, minimal CPU; **optional** |
| **Secure** | 0x04 | AES-256-GCM, 28-byte overhead | go-mumble-server Secure tier (TLS 1.3 + client cert required) |

**Lite mode** — Client sends `CryptoModes = 0x01`. Server responds with CryptSetup (empty key). UDP voice is cleartext; TCP control remains TLS-encrypted. Suitable for trusted LAN deployments.

**Legacy mode (standard Mumble)** — Client sends `CryptoModes = 0x02` or `0x03` (Lite \| Legacy). Server responds with CryptSetup (16-byte key + 16-byte nonces). UDP voice is encrypted with OCB2-AES128. Compatible with any standard Mumble server. Legacy is the default. Changing crypto in HA (Legacy ↔ Lite) forces a reconnect so the server negotiates the new mode.

**Secure mode** — Server sends CryptSetup with 32-byte key and 12-byte nonces. UDP voice uses AES-256-GCM (packet format: 12-byte nonce \|\| ciphertext \|\| 16-byte tag). go-mumble-server only negotiates Secure when the client advertises 0x04 and uses TLS 1.3 with a client certificate. This client accepts Secure CryptSetup when the server chooses it; use of Secure tier from the client (advertising 0x04) requires TLS 1.3 and client cert support (not yet implemented).

**CryptSetup** — Key length indicates mode: 0 = Lite, 16 = Legacy, 32 = Secure. Legacy nonce resync: client may send CryptSetup with only `client_nonce`; server replies with `server_nonce`. The client triggers proactive resync before the Legacy nonce wraps (~256 packets).

**OCB2 implementation** — The Legacy OCB2-AES128 codec (`mumble_ocb2.cpp`) is ported from [mumble-voip/grumble](https://github.com/mumble-voip/grumble) and must match its byte layout for interoperability with Mumble servers. Key requirements: GF(2^128) doubling uses block\[0\] as MSB (big-endian); partial-block length is encoded at bytes 14–15; polynomial 0x87 for reduction.

### TCP Wire Format

Every TCP message uses a 6-byte header:

```
┌──────────────┬────────────────────┬──────────────────┐
│ Type (u16be) │ Length (u32be)      │ Payload (bytes)  │
│ 2 bytes      │ 4 bytes            │ 0..8MB           │
└──────────────┴────────────────────┴──────────────────┘
```

Message types relevant to this client:

| Type | Name | Direction | Purpose |
|---|---|---|---|
| 0 | Version | Both | Protocol version, OS info, CryptoModes |
| 1 | UDPTunnel | Both | Voice data tunneled over TCP (fallback) |
| 2 | Authenticate | C→S | Username, password, codec support |
| 3 | Ping | Both | Keepalive and latency measurement |
| 5 | ServerSync | S→C | Session ID, welcome text, permissions |
| 7 | ChannelState | S→C | Channel tree |
| 9 | UserState | Both | User presence, channel membership |
| 15 | CryptSetup | S→C | Encryption key and nonces |
| 21 | CodecVersion | S→C | Supported codecs |

Message payloads use a field-tagged, length-delimited wire format (similar layout to Mumble protobuf). The implementation uses a minimal hand-written encoder/decoder — **no protobuf library** — to reduce flash and RAM usage.

### UDP Voice Packet Format

Client-to-server:

```
┌──────────────────────────────┬─────────────────┬───────────────────────┬───────────────┐
│ Header byte                  │ Sequence (varint)│ Payload len (varint) │ Opus frame    │
│ codec(3b) | target(5b)       │                  │ bit 13 = terminator  │               │
└──────────────────────────────┴─────────────────┴───────────────────────┴───────────────┘
```

Server-to-client (adds sender session):

```
┌──────────────┬──────────────────┬─────────────────┬───────────────────────┬───────────────┐
│ Header byte  │ Session (varint) │ Sequence (varint)│ Payload len (varint) │ Opus frame    │
└──────────────┴──────────────────┴─────────────────┴───────────────────────┴───────────────┘
```

- Codec field: `4` = Opus (the only codec this client supports).
- Target field: `0` = normal (current channel), `31` = server loopback (useful for testing).
- Varint encoding uses Mumble's **custom** format (not standard LEB128): the first-byte bit pattern determines byte count. Do not assume protobuf-style 7-bit groups.

This client uses the **legacy binary format**; the server also supports a modern wire format (Mumble 1.5+) but legacy is sufficient and widely compatible.

### UDP Ping

UDP connectivity is confirmed by a ping/echo exchange. The client sends a codec-type-1 packet (encrypted in Legacy mode); the server decrypts it, matches the session, and echoes it back. If no echo is received within the timeout, the client falls back to tunneling voice over TCP using UDPTunnel (message type 1). **ESP32-S3 Box, Box-3, and Voice PE (ESP-IDF)**: Use lwIP netconn for UDP. **Other boards (Arduino)**: WiFiUDP.

### Protocol Reference

For protocol details (TCP message catalog, UDP voice format, varint encoding, crypto modes), see the [Mumble protocol documentation](https://mumble.info/) and your server’s implementation (e.g. Murmur, go-mumble-server).

## Audio Pipeline

### Capture Path (Microphone to Network) — *Implemented*

```
I2S Mic ──► Ring Buffer ──► VAD ──► Echo Suppress ──► Opus Encoder ──► Voice Packet ──► UDP/TCP ──► WiFi TX
```

Implemented pipeline: ESPHome microphone component → ring buffer → energy-based VAD (threshold 200, 3-frame attack, 15-frame hangover) → echo suppression (TX suppressed while receiving or 100 ms after) → Opus encode (16 kHz mono, 16 kbps) → Mumble UDP voice packet → send via UDP or TCP tunnel fallback. Half-duplex I2S bus management: mic and speaker share the bus; `manage_i2s_bus()` coordinates handoff using `is_stopped()` to avoid "Parent I2S bus not free" errors. A short warmup delay (80 ms) is applied before starting the microphone when transitioning from speaker to mic, to ensure the I2S/ES7210 codec is ready.

### Playback Path (Network to Speaker) — *Implemented*

```
WiFi RX ──► UDP Packet ──► Parse Header ──► Opus Decoder ──► Mixer ──► Resampler ──► I2S Speaker
                                                                            │
                                                              AEC ref ◄─────┘
```

1. **UDP receive**: Voice packets arrive from the server containing another user's session ID, sequence number, and Opus frame.
2. **Jitter buffer**: Packets are held in a small buffer (~40 ms prebuffer, 320 ms capacity) to smooth arrival jitter. All available frames are flushed to the speaker's ring buffer each loop iteration; the I2S DMA handles real-time playout timing.
3. **Opus decoding**: libopus decodes the compressed frame to 16 kHz PCM.
4. **Mixing**: If multiple users are speaking simultaneously, their decoded PCM streams are summed.
5. **Resampling**: If the DAC runs at a different rate (e.g. 48 kHz for ES8311), a sample rate converter upsamples the 16 kHz PCM.
6. **I2S playback**: PCM samples are written to the I2S DMA buffer for the speaker/DAC. This output also feeds the AEC reference input.

### FreeRTOS Task Layout

| Task | Core | Priority | Responsibility |
|---|---|---|---|
| `mumble_control` | 0 | Medium | TCP/TLS connection, message handling, ping |
| `audio_capture` | 1 | High | I2S read, AEC, Opus encode, UDP send |
| `audio_playback` | 1 | High | UDP receive, jitter buffer, Opus decode, I2S write |
| `esphome_loop` | 0 | Medium | ESPHome component loop, HA API, entity updates |

Pinning the audio tasks to core 1 keeps them isolated from network and ESPHome overhead on core 0. A shared ring buffer with FreeRTOS queue notifications connects the capture/playback tasks to the network tasks.

### Acoustic Echo Cancellation

In always-on mode the speaker output will be picked up by the microphone, creating an echo loop. AEC is addressed by feeding the speaker's playback PCM as a reference signal to the echo cancellation algorithm:

- **ESP-SR AFE**: Espressif's audio front-end library includes AEC, noise suppression, and VAD. Runs on the ESP32-S3's dedicated vector instructions.
- **ESP-ADF AEC**: The Audio Development Framework provides an AEC pipeline element that can be inserted between I2S capture and the application.
- **Current implementation**: Half-duplex with echo suppression — when receiving voice (or within 100 ms after), transmit is suppressed. ESPHome's I2S component uses exclusive bus access, so mic and speaker take turns; `manage_i2s_bus()` coordinates the handoff.

### Microphone Array Support

Boards with multi-channel ADCs (ES7210 on ESP32-S3 Box / Box 3) can capture from 2-4 microphones simultaneously. The audio pipeline supports:

- **Beamforming**: Spatial filtering to focus on a direction and reject off-axis noise.
- **Channel selection**: Use a single preferred channel from the array.
- **Downmix**: Simple average or weighted sum of channels to mono.

The pipeline order is: multi-channel capture → beamforming/downmix (to mono) → AEC (speaker reference subtracted from mic) → Opus encode. Beamforming runs before AEC to provide the cleanest mono input for echo cancellation.

## ESPHome Integration

### External Component Structure

```
components/
  mumble/
    __init__.py               # ESPHome component registration, YAML schema
    mumble_component.h/.cpp   # Main component; settings, mic/speaker bus, PTT, mute pin
    mumble_client.h/.cpp      # MumbleClient (connection, protocol, messages)
    mumble_socket.h/.cpp      # TlsClient and UdpSocket (ESP-IDF or Arduino backend)
    mumble_audio.h/.cpp       # Audio pipeline (capture, playback, Opus, jitter buffer)
    mumble_protocol.h/.cpp    # Wire format encoding/decoding (TCP header, framing)
    mumble_messages.h/.cpp    # Message structs and marshal/unmarshal (all 27 types)
    mumble_varint.h/.cpp      # Varint encode/decode (Mumble custom format)
    mumble_permissions.h      # Permission constants (ACL, etc.)
    mumble_voice.h/.cpp       # Voice packet build/parse (UDP)
    mumble_channel_select.h/.cpp  # Optional HA channel select (server tree)
    mumble_diag.h/.cpp        # Diagnostics (ping, etc.)
    communicator_chime_data.h # Embedded PCM for communicator chimes
    mumble_gcm.h/.cpp         # AES-256-GCM for Secure mode (mbedtls)
    mumble_ocb2.h/.cpp       # OCB2-AES128 for Legacy UDP (ported from grumble)
    mumble_udp.h/.cpp        # UDP send/recv, ping, voice packet framing
```

**Framework backends**: The component uses a socket abstraction (`TlsClient`, `UdpSocket`) with two backends: **Arduino** (WiFiClientSecure, WiFiUDP) and **ESP-IDF** (esp_tls, lwIP **netconn** for UDP, BSD sockets for TCP). **ESP32-S3 Box, Box-3, and Voice PE** use ESP-IDF with lwIP netconn (`netconn_sendto`). **Generic, M5Stack Atom Echo, and others** use Arduino.

The component is loaded as an ESPHome external component. Connection settings (server, port, username, password, channel) can be inline or referenced from text entities; mode (always_on / push_to_talk) can be set in YAML or via an optional select entity. Username defaults to `esp32-<MAC>` on first run if not set; password has no default. All HA-linked values are editable in the HA UI and persisted to NVS. Changing server, username, password, or channel forces a reconnect. Wire a physical button to `mumble.microphone_enable` and `mumble.microphone_disable` for mic control (press = on, release = off). The `mumble.ptt_press` action toggles mic state. The `mumble.reset_config` action resets all config entities to defaults.

**Home Assistant server auto-detection** — The Mumble server address defaults to empty. When the device is adopted by Home Assistant (HA connects to the ESP via the ESPHome API), the config uses `api.on_client_connected`; if the server text entity is still empty, it is set to `client_address` (the HA server's IP). This supports the common case of running go-mumble-server as a Home Assistant addon on the same host. A manually set server is never overwritten (it persists in NVS). The component's `publish_empty_text_defaults()` ensures the server field shows `""` in HA instead of "unknown" when unset.

**Empty-state "unknown" workaround** — ESPHome's `TemplateText::setup()` only calls `publish_state()` when the restored/initial value is non-empty. Text entities with `initial_value: ""` (or omitted) never get a state published, so Home Assistant displays them as "unknown". The Mumble component works around this by calling `publish_empty_text_defaults()` during `setup()`, which force-publishes an empty string for any text entity that still has `has_state() == false`. Always use `initial_value: ""` in the YAML (not omitted) so the intent is clear, and rely on the component to publish the state.

**Boot-time restore of controls** — ESPHome template entities with `set_action` or `lambda` do not re-fire their actions when NVS values are restored on boot. Speaker Volume (template number) would lose its saved state without explicit handling. The fix uses two mechanisms:

1. **`on_boot` at priority `-100`** (runs after all template components have restored NVS values): reads the stored Speaker Volume and applies it via `speaker.volume_set`.
2. **`EsphomeSpeakerSink::start()` re-applies volume** — `speaker->set_volume(speaker->get_volume())` after `start()` ensures the DAC register matches the stored volume even if audio hardware re-initializes when the speaker starts.

```yaml
external_components:
  - source: { type: local, path: components }

# Optional: text/select entities for HA-editable settings (restore_value: true)
# Port uses text (not number) so it displays as integer in HA
text:
  - platform: template
    id: mumble_server_host
    name: "1. Server"
    mode: text
    optimistic: true
    restore_value: true
    initial_value: ""
  - platform: template
    id: mumble_server_port
    name: "2. Port"
    mode: text
    optimistic: true
    restore_value: true
    initial_value: "64738"
select:
  - platform: template
    id: mumble_mode
    name: "6. Mode"
    optimistic: true
    restore_value: true
    initial_option: "always_on"
    options: ["always_on", "push_to_talk", "communicator"]

# When HA connects, if server is empty it is set to client_address (HA IP) for addon use.
# Production configs also log via ESP_LOGI when setting server from client_address.
api:
  on_client_connected:
    - lambda: |-
        if (id(mumble_server_host).state.empty()) {
          id(mumble_server_host).make_call().set_value(client_address).perform();
        }

# Physical button: on_press -> mumble.microphone_enable, on_release -> mumble.microphone_disable
mumble:
  id: mumble_client
  server: ""              # empty by default; auto-filled from HA IP when adopted, or set manually
  port: 64738
  username: ""
  password: ""
  channel: "Root"
  server_text_id: mumble_server_host
  port_text_id: mumble_server_port
  # username_text_id, password_text_id, channel_text_id, crypto_select_id ...
  mode_select_id: mumble_mode
  microphone_id: box_mic  # optional; when set, enables transmit
  speaker_id: box_speaker
  mode: always_on
  mute_pin: GPIO38        # optional hardware mute switch
```

### YAML Configuration

| Key | Type | Default | Description |
|-----|---|---|---|
| `server` | string | `""` | Mumble server hostname or IP (or use `server_text_id`). Empty by default; when adopted by HA, the config can set it from `client_address` (HA IP). |
| `port` | int | 64738 | Mumble server port |
| `username` | string | optional | Username to authenticate with (or use `username_text_id`) |
| `password` | string | `""` | Server or user password |
| `channel` | string | `"Root"` | Channel to join after connect (default Root; empty = root) |
| `mode_select_id` | id | none | Select entity for mode (options: `always_on`, `push_to_talk`, `communicator`; overrides `mode` when set) |
| `mode` | enum | `always_on` | `always_on` or `push_to_talk` (fallback when no `mode_select_id`) |
| `server_text_id` | id | none | Text entity for server host (overrides `server` when set) |
| `port_text_id` | id | none | Text entity for port (displays as integer in HA) |
| `username_text_id` | id | none | Text entity for username |
| `password_text_id` | id | none | Text entity for password |
| `channel_text_id` | id | none | Text entity for default channel |
| `crypto_select_id` | id | none | Select entity for crypto (`legacy` or `lite`) |
| `microphone_id` | id | none | ESPHome microphone component for capture (required for transmit) |
| `speaker_id` | id | none | ESPHome speaker component for playback |
| `ptt_pin` | pin | none | GPIO for push-to-talk button (optional; wire button to mumble.microphone_enable/disable in YAML) |
| `mute_pin` | pin | none | GPIO for hardware mute switch (LOW = muted; syncs self_mute and mic). Not used on Box/Box-3 (mute circuit is hardware-isolated). |
| `crypto` | enum | `legacy` | Crypto mode: `legacy` (default, OCB2-AES128) or `lite` (cleartext UDP). Use `crypto_select_id` for HA entity. Changing crypto forces reconnect. |
| `ca_cert` | string | (empty) | Optional PEM of CA certificate for server verification. When set, TLS verification is enabled; when empty, insecure mode (trusted LAN only). |
| `bot_mode` | bool | false | When true, Authenticate sends `client_type=1` (bot). |
| `on_communicator_end` | automation | none | Fired when communicator sequence ends (timeout or cancel); wire to play close chime (Box/Box-3). |
| `on_text_message` | automation | none | Fired when a text message is received (e.g. for bot/automation). |

**ESP32-S3 Box / Box-3 / Voice PE (ESP-IDF)** — These use `framework: type: esp-idf` with lwIP netconn for UDP. First flash must be via USB, not OTA.

### Home Assistant Entities

**Configuration entities** -- editable from the HA UI, persisted to NVS:

| Entity ID | Platform | Description |
|---|---|---|
| `text.mumble_server_host` | `text` | Server hostname or IP |
| `text.mumble_server_port` | `text` | Server port (integer, no decimals) |
| `select.mumble_mode` | `select` | Mode: `always_on`, `push_to_talk`, or `communicator` |
| `text.mumble_username` | `text` | Username |
| `text.mumble_password` | `text` | Password (mode: password) |
| `text.mumble_channel` | `text` | Channel to join on connect |
| `select.mumble_crypto` | `select` | Crypto: `legacy` or `lite` |

When server, username, password, or channel is changed in HA, the client disconnects immediately and reconnects with the new settings. YAML values serve as initial defaults that are overridden once HA values are set. Channel name lookup is case-insensitive (e.g. `root` matches `Root`).

**Controls**:

| Entity ID | Platform | Description |
|---|---|---|
| `number.mumble_speaker_volume` | `number` | Speaker volume 0–100 (persists via NVS; applied on boot) |
| `switch.speaker_power` | `switch` | Speaker Power — PA enable (Box/Box-3 GPIO46; Voice PE GPIO47; persists) |

**Diagnostics**:

| Entity ID | Platform | Description |
|---|---|---|
| `sensor.wifi_signal` | `sensor` | WiFi RSSI (dBm) |
| `binary_sensor.mumble_connected` | `binary_sensor` | Connected to Mumble server |
| `sensor.mumble_ping` | `sensor` | Round-trip ping time to server in ms |
| `binary_sensor.mumble_voice_active` | `binary_sensor` | Voice Received: true while voice is being received |
| `binary_sensor.mumble_voice_sending` | `binary_sensor` | Voice Sending: true while the device is transmitting |
| `button.mumble_reset_config` | `button` | Reset all config to defaults (server to empty, port, username, password, channel, mode, crypto) |

**Runtime entities**:

| Entity ID | Platform | Status | Description |
|---|---|---|---|
| `number.mumble_speaker_volume` | `number` | Implemented | Speaker volume 0–100 (NVS restore on boot) |
| `switch.speaker_power` | `switch` | Implemented | Speaker Power — PA enable (Box/Box-3, Voice PE) |
| `binary_sensor.mumble_connected` | `binary_sensor` | Implemented | Connection status (Diagnostics) |
| `binary_sensor.mumble_voice_active` | `binary_sensor` | Implemented | Voice Received (Sensors, with Microphone) |
| `select.mumble_channel` | `select` | Optional | Channel select with server options (`channel_select_id`) |
| `binary_sensor.mumble_voice_sending` | `binary_sensor` | Implemented | Voice Sending: true while transmitting |

## Hardware Abstraction

Board-specific details (pin assignments, codec I2C addresses, I2S parameters) are isolated in per-board YAML packages and C++ board profiles. The audio pipeline code operates on abstract interfaces:

- **MicrophoneSource**: Provides mono 16 kHz PCM frames. Implemented per-board to handle I2S configuration, multi-channel downmix, and PDM vs standard I2S.
- **SpeakerSink**: Accepts mono 16 kHz PCM frames and handles resampling and I2S output to the DAC/amplifier.
- **BoardConfig**: Pin map, I2C bus configuration, LED strip parameters, button/touch GPIO.

### Board Profiles

**ESP32-S3 Box 3** (**ESP-IDF framework**)
- Framework: `type: esp-idf`; lwIP netconn for UDP; min ESPHome 2026.7.0
- I2S: LRCLK=GPIO45, BCLK=GPIO17, MCLK=GPIO2, DIN=GPIO16, DOUT=GPIO15
- I2C: SCL=GPIO18, SDA=GPIO8
- ADC: ES7210 (4-ch, 16 kHz, 16-bit)
- DAC: ES8311 (48 kHz, mono)
- Speaker Power (PA enable): GPIO46

**ESP32-S3 Box** (older revision, **ESP-IDF framework**)
- Framework: `type: esp-idf`; lwIP netconn for UDP; min ESPHome 2026.7.0
- I2S: LRCLK=GPIO47, BCLK=GPIO17, MCLK=GPIO2, DIN=GPIO16, DOUT=GPIO15
- I2C: SCL=GPIO18, SDA=GPIO8
- ADC: ES7210 (4-ch, 16 kHz, 16-bit)
- DAC: ES8311 (48 kHz, mono)
- Speaker Power (PA enable): GPIO46

**Home Assistant Voice Preview Edition** (**ESP-IDF framework**)
- Framework: `type: esp-idf`; lwIP netconn for UDP; min ESPHome 2026.7.0
- Board: `esp32-s3-devkitc-1`, 16 MB flash, octal PSRAM 80 MHz
- I2C: SDA=GPIO5, SCL=GPIO6 (codec + XMOS)
- Mic I2S (secondary): DIN=GPIO15, BCLK=GPIO13, LRCLK=GPIO14; XMOS Voice Kit (reset GPIO4, I2C 0x42)
- Speaker I2S (secondary): DOUT=GPIO10, BCLK=GPIO8, LRCLK=GPIO7; AIC3204 DAC @ 48 kHz with `resampler` for 16 kHz Mumble/chime
- Speaker Power (amp enable): GPIO47
- Center button (PTT/Communicator): GPIO0 (inverted)
- Mute slider: GPIO3
- Jog wheel (volume): GPIO16 / GPIO18
- LED ring: GPIO21 (WS2812 ×12), power GPIO45
- Jack detect: GPIO17 (diagnostic sensor)
- Config: `esphome/home-assistant-voice-pe.yaml`; vendored `components/voice_kit/`

**Onju Voice**
- I2S: LRCLK=GPIO13, BCLK=GPIO18, DIN=GPIO17, DOUT=GPIO12
- Mic: SPH0645 (I2S, mono)
- Amp: MAX98357A (I2S, mono)
- Mute: GPIO38 (switch), GPIO21 (amp enable, inverted)
- LEDs: GPIO11 (SK6812, 6 LEDs)
- Touch: GPIO4 (vol-), GPIO2 (vol+), GPIO3 (action)

**M5Stack Atom Echo**
- I2S: DIN=GPIO23 (PDM mic)
- Speaker: external I2S DAC (DOUT pin board-dependent; see M5Stack docs)
- Compact; no touch or LED ring

**Generic**
- All pins user-defined in YAML
- Assumes single I2S mic + single I2S speaker

## Dependencies

| Dependency | Version | Purpose |
|---|---|---|
| ESP-IDF | 5.x (via ESPHome) | SoC framework (Box/Box-3/Voice PE use esp-idf + lwIP netconn; others use Arduino on ESP-IDF base) |
| ESPHome | 2026.7.0+ (`requirements.txt` pins 2026.7.1) | Component framework, HA integration, OTA |
| micro-opus | local `lib/micro-opus/` **0.4.1** | Opus audio codec; heap pseudostack, PSRAM, Xtensa DSP; based on esphome-libs/micro-opus |
| mbedTLS | (bundled with ESP-IDF) | TLS for Mumble control channel; OCB2-AES128 for Legacy; AES-256-GCM for Secure |
| ESP-ADF | optional | ADF pipeline for full-duplex I2S |
| ESP-SR | optional | AEC, noise suppression, beamforming |

The build uses ESPHome/PlatformIO. The Opus library is **vendored locally** in `lib/micro-opus/` — a pre-patched copy of [esphome-libs/micro-opus](https://github.com/esphome-libs/micro-opus) v0.4.1 with heap-based pseudostack (avoids stack overflow from alloca-based builds), PSRAM-aware allocation, and Xtensa LX7 optimizations for ESP32-S3. Install the host toolchain with `pip install -r requirements.txt` (Python 3.12+).

## Key Technical Risks

| Risk | Impact | Mitigation |
|---|---|---|
| Opus encode/decode CPU cost | Audio dropouts or high latency | Use 16 kHz narrowband mode (~3 ms encode per 20 ms frame on S3). Pin audio tasks to dedicated core. |
| I2S bus sharing | Mic and speaker contend for same bus | Half-duplex via `manage_i2s_bus()`: wait for `is_stopped()` before starting the other. Echo suppression during receive. |
| AEC quality | Echo leaks in always-on mode | Start with ESP-SR AFE. Allow fallback to push-to-talk if AEC is insufficient for a board. |
| RAM budget | Opus + TLS + ESPHome may exceed SRAM | Use PSRAM for audio buffers and Opus state. Optimize TLS buffer sizes. Target boards with 8 MB PSRAM. |
| TLS handshake time | Slow reconnects | Cache TLS sessions. Use TLS 1.2 with minimal cipher suite. |
| Wire format encoding | Compatibility with upstream Mumble | Hand-written encoder (field-tagged, no protobuf lib) matched to Mumble wire format. Integration test against live server. |
| Legacy crypto (OCB2-AES128) | Compatibility with server | Implemented; ported from grumble. Byte layout and GF operations match standard Mumble. Lite and Secure (AES-256-GCM) supported; optional `ca_cert` for TLS verification. |

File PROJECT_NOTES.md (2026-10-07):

# Intercom boerderij — project notes

Summary of the claude.ai project "Intercom boerderij"
(https://claude.ai/project/01a0be9b-925f-714b-8b62-d522bc2748fb) and the Claude Design
project "Art Deco Intercom Grill"
(https://claude.ai/design/p/af2fbe00-a71f-4dd4-8ccf-62192279e134), pulled 2026-10-01.

## Goal

A home intercom that is **near-instant** (hard requirement) and integrates with
**Home Assistant** (strongly wanted: listen to a room, use the speakers from HA).
Form factor: a wall-mounted box with a brass front plate. The plate has **four room
buttons** (3 children's rooms, 1 workshop), each with an LED ring.

## How the design evolved

1. **Nov 2025: SIP/paging route (abandoned).** FreePBX/Asterisk, an ESP32 button panel
   and Grandstream PoE paging speakers (GSC3506).
2. **Sep 2026: ESP32 + Mumble route (current).** ESP32-P4 boxes running a Mumble
   client, one Mumble server for the house, with Mumble channels used to route to rooms.
3. **Oct 2026: serverless route, lanicom (in progress).** No server, no HA dependency, so
   friends can use it. Boxes discover each other by authenticated broadcast and send Opus
   by encrypted unicast. Same board and ESPHome stack. See `lanicom/PLAN.md`.

## Decisions made

| Area | Decision |
| --- | --- |
| Board | **Waveshare ESP32-P4-ETH** (sku ESP32-P4-POE-ETH, arrived 2026-10-01). Ethernet, PoE via a module that sits on top of the P4, 32MB PSRAM, onboard mic, codec, speaker header. No Wi-Fi. |
| Speaker | Onboard amp header (8Ω, 2W). Fine as is. |
| Mumble server | Official **Murmur** container (`mumblevoip/mumble-server`). go-mumble-server (same author as the client) is the alternative. |
| Firmware | **ESPHome**, using dchote/esp32-mumble as an external component, ported to the P4. Not plain ESP-IDF, and no MQTT (see below). |
| Buttons | Illuminated panel-mount momentary switch: **M19 thread, Φ22 bezel**, 36mm long, LED ring. Four of them. |
| Front plate | 180 × 90 mm, **3mm brass**, R3 corners, laser-cut by laseropmaat.nl. Fan/arches/chevron art-deco grille above a row of 4 buttons along the bottom. 4 × Ø3 countersunk mounting holes, 6mm from the edges. |
| Enclosure | Wooden box made by hand router, in **two halves**: a back tray for the board, speaker and PoE, and a front piece with a plate rebate plus relief pockets so each switch nut can be tightened. Screwed together, not glued. |

## Firmware: why ESPHome and not ESP-IDF + MQTT

dchote/esp32-mumble (last commit 2026-07-23, actively maintained) **is already an ESPHome
external component** for the **ESP32-S3**. The Sep 20 chat was right. The Oct 1 chat was
wrong: the repo is not an old standalone ESP-IDF project for the original ESP32. The
"standalone ESP-IDF + MQTT" advice rested on that mistake.

- ESPHome talks to HA over its own native API. The component already exposes mode
  (Always On / PTT / Communicator), mute, volume, channel select, server settings,
  connection, ping and voice-activity diagnostics, plus OTA updates. MQTT would only
  rebuild that by hand.
- Four room buttons are easy in YAML: on press, set the channel and start talking;
  on release, stop.
- Board configs for the ESP-IDF framework (Box, Box-3, Voice PE) already use the same
  ES8311 DAC through ESPHome's `audio_dac` / `i2s_audio` components.

### What the P4 port actually involves (from reading the source)

1. **Opus:** `lib/micro-opus/library.json` hard-codes `-DOPUS_XTENSA_LX7` and
   `celt/xtensa/mathops_lx7.c`. For RISC-V, make those conditional and use the
   generic C path.
2. **Wi-Fi assumptions:** `mumble_component.cpp` calls `esp_wifi_set_ps()` and reads the
   MAC from `ESP_MAC_WIFI_STA`. Guard these for Ethernet (use the Ethernet MAC).
   `mumble_client.cpp` waits 5 s for "Wi-Fi stability". It's harmless, but the name
   is now misleading.
3. **Board YAML:** a new `esphome/waveshare-esp32-p4-poe.yaml` with `ethernet:` instead of
   `wifi:`, PSRAM, I2S pins, the ES8311 codec, and the 4 buttons and LEDs. The
   ESP-IDF networking path (lwIP netconn) is network-agnostic.
4. Check that **ESPHome supports the P4** well enough for Ethernet + I2S. The repo pins
   ESPHome 2026.7.1.
5. Worth opening a discussion or PR upstream, since the maintainer welcomes new hardware.

## Front plate DXF check (`~/Downloads/intercom-grill-arches.dxf`)

The two copies in Downloads are identical. The file is 180 × 90 mm, with layers `CUT` and
`INFO_CSK` (countersink note for the firm).

- **The button holes are Ø16** (r=8, at x = 42/74/106/138, y = 14). The M19 switches need
  **Ø19.3–19.5**. Fix this in the design's buttonDiameter tweak before ordering.
- With Φ22 bezels, a 32mm pitch leaves 10mm between bezels. The bezel's bottom edge
  sits 3mm from the plate edge, so check that the wooden frame doesn't overlap it.
- Mounting holes are Ø3.0. M3 screws need about Ø3.2–3.4.
- **Pattern vs. 3mm brass:** at 35mm repeat, only **Chevron** is comfortably cuttable
  (1.7mm slots, 2.1mm webs). Arches and Fan scallop need about 55mm repeat or thinner
  brass. The design is currently set to a 55mm fan width with a 2mm minimum web. Ask
  laseropmaat their minimum slot and web width for 3mm brass.

## Open items

- [ ] Set the button holes to Ø19.3–19.5 and re-export the DXF.
- [ ] Measure the switch's engageable thread length and nut size across flats (sets the land and pocket size).
- [ ] Ask laseropmaat about the minimum slot and web width; pick the pattern and repeat size.
- [ ] PoE infrastructure isn't there yet. Power over USB-C for now; Ethernet works without PoE.
- [x] Bring-up firmware (`esphome/p4-bringup.yaml`) flashed 2026-10-01. Chip rev v3.2, 32MB PSRAM, ES8311 up, Ethernet gets an IP (DHCP). Logs need `logger: hardware_uart: UART0` (USB-C is a CH343 bridge).
- [ ] Adopt in HA; test the speaker (Play Test Tone) and mic (Mic Peak/RMS). Wire a test button to GPIO20.
- [x] Port esp32-mumble to the P4 (2026-10-01): working copy in `esp32-mumble/`, board config
      `esp32-mumble/esphome/waveshare-esp32-p4-poe.yaml`. Builds and runs: Ethernet up, Opus
      encoder/decoder init, mic enabled. Uses ESPHome's **native esp-idf toolchain**, because
      PlatformIO's (pioarduino 55.03.39) can't link rev3 P4 builds (missing `sections.rev3.ld.in`).
      `lib/micro-opus/CMakeLists.txt` registers Opus as an IDF component for that toolchain.
- [x] Murmur 1.5 (official Docker image) runs on **meklit** (192.168.188.45:64738), compose file in `~/mumble-server`.
      The P4 connects: TLS, OCB2-AES128 crypto, UDP voice channel all confirmed (2026-10-01).
- [x] **Voice TX works end to end** (2026-10-01): board -> Murmur -> pymumble listener received audio.
      Mic fix: drop `use_microphone: true` from the es8311 config. In ESPHome's driver it selects a
      PDM *digital* mic (REG14 bit 6); this board's mic is analog, and the driver enables that without it.
- [x] WireGuard for remote access (2026-10-01): `wg1` on meklit (10.66.66.1/24, UDP 51820, enabled at boot),
      phone peer 10.66.66.2, limited to meklit only. Mumla server: 10.66.66.1:64738. meklit's existing
      `wg0` (an unrelated, disabled client config) left untouched.
- [x] Remote access works (2026-10-03): Mumla on the phone connects over WireGuard. Double NAT:
      Double NAT: the ISP router (192.168.2.254) forwards UDP 51820 -> FRITZ!Box (192.168.2.1), which
      forwards to meklit **192.168.188.45**. Watch out: the FRITZ!Box has a stale older device entry also
      named "meklit" (different IP/MAC); the sharing must use the current one. The endpoint in the phone
      config is the home's public IP, which may change: consider DynDNS.
- [ ] Speaker/RX test once a speaker is connected (MX1.25; "JST 1.25" hobby cables are usually PicoBlade-compatible, JST GH is not).
- [x] Voice quality (2026-10-03), measured with `tools/voicetest` (speech -> Bluetooth speaker in the closet ->
      P4 -> Mumble -> Whisper word error rate). Dutch test sentence: WER 9%, only the first word ("Hallo") lost.
      Fixes: VAD no longer raises its noise floor during speech, hangover 0.3 -> 0.8 s, push-to-talk bypasses
      VAD and its calibration, mic gain 72 dB -> 30 dB preamp + 24 dB digital (HA settings "Mic Preamp" /
      "Mic Digital Gain"). meklit's laptop speakers are useless as a test source (54% WER even on its own mic).
- [x] Choppy audio in Mumla at home was the tunnel, not the board: with WireGuard on over home Wi-Fi the traffic
      hairpins through the ISP router and loses ~65% of packets. Direct to 192.168.188.45: 0% loss.
      At home use the LAN address; WireGuard only when away.
- [x] **Mumla playback fixed** (2026-10-03): the board stepped the voice sequence by 1 per 20 ms packet and
      reset it to 0 each utterance. Mumble counts 10 ms frames (+2 per packet), and Mumla's jitter buffer
      dropped the mistimed packets. Fixed in `send_voice_packet()`. This is an upstream esp32-mumble bug that
      affects every board: worth reporting/PR. Mumla now "so much better"; over the tunnel at home slightly worse but usable.
- [x] First word (2026-10-03): 200 ms pre-roll in always_on, `mic_warmup: 50ms` (new option, default 200 ms).
      The lost "Hallo" in tests was the Bluetooth speaker muting on digital silence: test clips are now padded
      with soft noise. Dutch sentence: 0% WER in both modes.
- [x] Opus sweep (Harvard sentences, PTT): WER 4-7% at 16k/c1, 24k/c5 and 32k/c10 alike (run-to-run noise).
      Encode time per 20 ms frame: 2.4 / 5.5 / 8.8 ms. Kept 16 kbit/s, complexity 1 pending a listening A/B.
      Settings "Opus Bitrate" / "Opus Complexity" are live-adjustable in HA.
- [x] PTT button on GPIO22 (2026-10-03): button to GND, internal pull-up, active low. TX starts ~60 ms after the press.
      Never wire a GPIO to VBUS/VSYS (5 V): the P4 pins are 3.3 V only.
      2026-10-06: PTT moved to GPIO23, button 1 on the carrier board (buttons 1-4 = GPIO23/22/21/20 in header order).
      A breadboard button on GPIO22 must move to GPIO23 with the new firmware.
- [x] Button pairing (2026-10-07, lanicom v1.1, docs/buttons.md): four buttons with rings, one partner each.
      A fresh box has nothing linked and plays only Home Assistant; hold a button 5 s on two boxes to link
      them. The old fixed-target PTT and the "Talk" switch are gone. Also: boot sweep, per-ring and night
      brightness (SNTP clock), uptime. Host-tested; not yet tried on hardware.
- [ ] Upstream PR https://github.com/dchote/esp32-mumble/pull/2 (branch `p4-support` on haarts/esp32-mumble,
      worktree /home/harm/prj/esp32-mumble-pr): P4 support, sequence fix, VAD. `esp32-mumble/` here is a git
      subtree identical to that branch; after merge, `git subtree pull --prefix=esp32-mumble <upstream> main`.
- [ ] lanicom (2026-10-06): spec, C core, Python CLI and HA integration done and tested off-device.
      Still to do on the board: flash `lanicom/esphome/lanicom-p4.yaml`, talk with `lanicom talk` on a laptop,
      and measure latency with and without `tools/make_lowlatency_i2s.py`. Stock ESPHome I2S queues about 50 ms
      on the speaker (5 × 10 ms DMA, preloaded), so expect about 120 ms mouth-to-ear on stock and about 70 ms
      with the override.
- [x] lanicom on the P4 (2026-10-06): flashed over the network (the old Mumble firmware's OTA had no password),
      found the laptop and verified it in seconds (RTT 2.3 ms over Wi-Fi). The PTT button on GPIO22 talks to the
      laptop's speakers, "perfectly". Voice test 0% WER. Click test, board sending half: ~34 ms stock, ~22-27 ms
      with the low-latency I2S override. The override is **not** used: first find out whether ~120 ms
      mouth-to-ear (estimated) is noticeable in half duplex. Fixed on the board: the speaker blocked the mic after
      playback. Laptop needs `ufw allow 47100/udp`. Next: a speaker on the board, then two boxes in different rooms.
- [ ] In HA: remove the old `intercom-p4-bringup` device, adopt `esp32-mumble-p4-e80332` (no API encryption yet).

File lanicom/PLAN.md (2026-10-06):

# lanicom: serverless LAN intercom (revised plan)

This is the plan for the serverless follow-up to the Mumble route. It revises
the first draft after a critical review (section 1) and records what has been
built and what is still open (section 5).

**Goal:** push-to-talk intercom devices on one LAN (wired or Wi-Fi) that find
each other and talk directly. There is no Mumble server and no Home Assistant
dependency. Devices can be added or removed at will. Home Assistant can join as
an ordinary peer. Friends can run it with zero infrastructure.

## 1. Review of the first draft: what changed and why

| # | First draft | Problem | Now |
|---|---|---|---|
| 1 | Raw **ESP-IDF** firmware with its own AP + HTTP provisioning page; OTA deferred | This repo already chose ESPHome, for good reasons (PROJECT_NOTES.md). The P4 audio path (ES8311 quirks, mic gains, micro-opus on RISC-V, PTT) is proven there. Raw IDF would redo all of that, plus provisioning, OTA, logging and a web UI. | An **ESPHome external component** (`esphome/components/lanicom`). Provisioning is ESPHome's `web_server` with a password text entity. OTA comes free. Friends flash from a browser. HA stays optional (`api:` with `reboot_timeout: 0s`). |
| 2 | Nonce = random 64-bit epoch ‖ seq, one key shared by all devices | All devices share one (key, nonce) space, so a single epoch collision anywhere leaks plaintext and allows forgery. Safety rests entirely on the boot-time RNG. | **Per-sender keys** (HKDF with `sender_id`), so devices can't collide. The epoch is a **persisted boot counter ‖ random**, so one device can't repeat even with a bad RNG. |
| 3 | Replay of an old session: check `unix_ms` in TalkStart if SNTP is available, otherwise "accept and log" | A serverless LAN often has no reliable time, so in practice nothing is checked. The check also covers TalkStart only, not the audio packets themselves. | **Epoch verification by challenge/echo** (PROTOCOL.md §4). A receiver accepts a new epoch only after the sender echoes a fresh random challenge. Recorded sessions can't be replayed, even to a freshly rebooted receiver, and no clock is needed. It costs one round trip at discovery. |
| 4 | Discovery by mDNS browse; `net` hint in TXT | mDNS is multicast, the very thing the draft calls unreliable on Wi-Fi. Browsing is clunky on ESP-IDF and needs `zeroconf` in Python. The `net` TXT record lets anyone group devices by network. Wrong-key devices still "appear". | **Authenticated broadcast `Hello`** every 5 s, plus optional static peers for routed networks. Wrong-key devices see only noise, and the protocol surface is smaller. mDNS is kept only as an advertisement for HA's zeroconf discovery. |
| 5 | No room for a key id ("leave a byte free" was an open question) | Changing the header later breaks compatibility. | The header has a 2-byte **`key_id`**, which drops foreign traffic cheaply and allows key rotation later. The header is still 20 bytes; the magic number was dropped in its favour. |
| 6 | TalkStart sent 3×; receivers dedupe; it carries `unix_ms` | If all three are lost, should the audio play? The draft didn't say. | Audio packets are **self-describing**. TalkStart/TalkStop are informational only (UI, LEDs, HA events). |
| 7 | The jitter buffer key wasn't specified | The header `seq` also counts packets to *other* peers, so seq gaps don't mean loss. | The jitter buffer orders frames by payload **`ts`** (48 kHz ticks) and never by `seq`. |
| 8 | Unicast fan-out: one copy per peer | Not wrong, but each copy would be sealed separately. | **Seal once, send N identical copies** (same nonce, same plaintext). |
| 9 | 10 ms frames everywhere | On Wi-Fi that is 100 packets/s per peer, each with about 72 bytes of overhead, so airtime grows with the number of peers. | 10 ms by default. 20 ms is allowed, and every receiver accepts 10 to 60 ms frames (the length comes from the Opus packet). |
| 10 | protobuf + nanopb codegen | A code generator in the firmware build for five tiny messages. Generated Python code is tied to the protobuf runtime version, which HA pins. | `spec/lanicom.proto` stays the normative schema. **Hand-coded** codecs in C and Python are tested against the official protobuf runtime (2000 random messages, plus fuzzing). |
| 11 | HA gets talk events (TalkStart) | HA doesn't play audio, so it never receives TalkStart: those only go to audio recipients. | A **`MONITOR`** capability bit. Talk metadata goes to every monitor as well; audio doesn't. |
| 12 | 1 PTT button | The front plate has **four room buttons** (PROJECT_NOTES.md). | Targets are `all` or `device:<id>`, and each button maps to one (see the YAML; pairing in docs/buttons.md). |
| 13 | ≤ 50 ms wired / ≤ 80 ms Wi-Fi p95 | Not reachable with stock ESPHome audio. Its I2S speaker preloads 5 × 10 ms of DMA (every write waits about 50 ms) and the mic reads in 16 ms blocks. See §4. | Measure first (milestone 7). An opt-in low-latency `i2s_audio` override is generated by `esphome/tools/make_lowlatency_i2s.py` (3 × 5 ms speaker DMA, 5 ms mic reads). The targets are revised in §4. |
| 14 | Opus library: `esp_audio_codec` vs libopus (open question) | Already answered in this repo: micro-opus runs on the P4 (2.4 ms per 20 ms frame at complexity 1). | Use **`esphome/micro-opus`** (the registry version ESPHome uses). `opus_path:` can point at the vendored copy in `esp32-mumble/lib/micro-opus` instead. |
| 15 | Python lib usable from HA | A custom integration can't depend on an unpublished package. | The library is vendored into the integration by `ha/sync_lib.py`, and CI checks that the copy is current. |
| 16 | "Pulling a cable never affects others" | Discovery didn't say how dead peers go away. | Peers expire after 30 s of silence, or immediately on a clean `bye`, which is sent by unicast only. A broadcast `bye` would have re-created the departed peer as an unverified stranger; the C tests caught that. |

Kept as in the draft: one UDP port, ChaCha20-Poly1305, a 20-byte header as
AAD, Opus 16 kHz VOIP with in-band FEC and PLC, an adaptive jitter buffer
(20 ms target, 60 ms ceiling), mixing of concurrent talkers, half-duplex
operation, and multicast as an option for wired installs only.

## 2. Architecture

```
  broadcast Hello (authenticated) ── discovery + liveness, challenge/echo verifies epochs
                     │
 ┌──────────┐  UDP 47100: [ver|type|key_id|sender|epoch|seq] + ChaCha20-Poly1305   ┌──────────┐
 │ P4 board │ ◄────────────────────────────────────────────────────────────────► │ P4 board │
 └──────────┘      CONTROL (protobuf: Hello, TalkStart, TalkStop) / AUDIO (Opus)  └──────────┘
        ▲                                                                              ▲
        └──── lanicom CLI (Linux/macOS) ──── Home Assistant (CAPTURE + MONITOR peer) ──┘
```

| Path | What |
|---|---|
| `spec/PROTOCOL.md`, `spec/lanicom.proto` | Normative protocol |
| `spec/vectors/lanicom-v1.json` | Test vectors (keys, packets, invalid packets, control, replay), generated by `python/tools/gen_vectors.py` from independent primitives |
| `lanicom-core/` | Portable C99 protocol engine: crypto (mbedTLS), packets, replay window, control codec, jitter buffer, mixer, peer table and verification. No sockets or clocks. Host tests run under ASan/UBSan. It is also an ESP-IDF component. |
| `esphome/components/lanicom/` | ESPHome glue: lwIP socket task, audio task (Opus, mic → frames, mixer → speaker), I2S bus arbitration, actions and triggers |
| `esphome/lanicom-p4.yaml` | Waveshare P4 board config |
| `python/` | Reference implementation (asyncio) and `lanicom` CLI: `keygen`, `list`, `listen`, `talk`, `record`, `send` |
| `ha/custom_components/lanicom/` | HA integration: config flow, per-device entities, `lanicom.announce`, talk events |

## 3. Security model

- **Assets:** the audio, and the ability to make a device speak.
- **Attacker:** anyone on the LAN without the key. They see sender ids, timing
  and sizes, but can't decrypt, inject, replay (§1 #3) or even appear in the
  peer table.
- **Not covered (v1):** a key holder can impersonate any device; there are no
  per-device identities. Mitigation for later: Noise-IK handshakes with
  per-device static keys.
- **Management plane:** the ESPHome API, the web page and OTA are what an attacker would
  go after. With them, anyone on the LAN could set their own network key and switch
  "Talk" on, turning the box into a room bug. The board YAML therefore requires API
  encryption, web auth and an OTA password (`secrets.yaml`).
- **Key handling:** keys are 125-bit random strings (`lanicom keygen`, optional
  QR), stretched with PBKDF2 (100k iterations). The key sits in ESPHome
  preferences (flash) and isn't encrypted unless flash encryption is enabled.
  Anyone with physical access to a board can extract it.

## 4. Latency budget (mouth to ear, one hop, wired)

| Stage | Stock ESPHome | `make_lowlatency_i2s.py` | Notes |
|---|---|---|---|
| Mic DMA read block | 16 | 5 | `READ_DURATION_MS` |
| Fill one frame | 10 | 10 | 20 ms frames add 10 |
| Opus lookahead (SILK, 16 kHz) | ~5 | ~5 | |
| Encode (P4, complexity 3) | ~2 | ~2 | measured 2.4 ms / 20 ms at c1 |
| Network (wired / Wi-Fi) | <1 / 2–10 | <1 / 2–10 | |
| Jitter buffer target | 20 | 20 (10 on wired) | adapts up to 60 |
| Playout tick alignment + prime | ~5 + 10 | ~5 + 10 | could be paced by DMA events instead |
| Speaker ring + DMA | ~50 | ~15 | stock: 5 × 10 ms preloaded |
| **Total (estimate)** | **~120** | **~70 (~60 with a 10 ms jitter target)** | |

Measured on a host (loopback, `pytest lanicom/python -s`): crypto plus network
takes 0.3 ms p50, and send-to-playout takes 20 ms, which equals the jitter
target. The device stages above are estimates until milestone 7.

**Measured on the P4 (2026-10-06,** `tools/voicetest/clicktest.py`**):** the board's sending half,
from a click at the laptop speaker next to the board to its packet back at the laptop
over Wi-Fi. That covers mic DMA, frame, Opus and the network.

| Build | Median per run | Spread within a run |
|---|---|---|
| Stock ESPHome I2S | 35.6, 33.8 ms | ~8 ms: two clusters, set by where a click falls in the 16 ms mic block |
| `make_lowlatency_i2s.py` | 22.4, 27.0 ms | ~2 ms |

This agrees with the estimates above: about 35 ms stock against ~34–38 estimated.
Laptop-side timing (PipeWire) is uncertain by about ±5 ms. The voice test
(`tools/voicetest/run-lanicom.sh`) gives 0% WER on both builds. The receiving half
(jitter buffer and speaker DMA) is still unmeasured: the board has no speaker yet.

**Revised targets:** stock ≤ 130 ms p95, low-latency I2S ≤ 75 ms p95 (wired).
Wi-Fi gets +20 ms. Getting to ≤ 50 ms would also need playout paced by the
I2S DMA events and a 10 ms jitter target. That is feasible, but only after
the measurements. For reference, ITU-T G.114 puts one-way delay below 150 ms
as fine for conversation.

## 5. Milestones and status

| # | Milestone | Status |
|---|---|---|
| 1 | Spec, proto, vectors | **Done.** PROTOCOL.md, lanicom.proto, 3 keys, 4 packets, 9 invalid packets, 9 control and 4 replay vectors. |
| 2 | C core with host tests | **Done.** 261 checks under ASan/UBSan: vectors, codec fuzzing, jitter, mixer, and engines on an in-memory LAN (discovery, wrong key, expiry, replay after restart, id collision, multicast, monitor). It cross-compiles for the P4 with `-Werror` against ESP-IDF 5.5.5. |
| 3 | Python library and CLI | **Done.** 35 tests: vectors, protobuf cross-check, real-UDP nodes on 127.0.0.x, a loopback latency test, Python↔C interop through `lanicom_tool`, and a CLI send→record end-to-end test. |
| 4 | Firmware bring-up | **Code written; needs the board.** `esphome compile lanicom-p4.yaml` builds (ESPHome 2026.7.1, ESP-IDF 5.5.5): RAM 20.7%, flash 11.7% (947 KB). The only warnings come from micro-opus. CI (`.github/workflows/lanicom.yml`) runs every test and the firmware build on each push. |
| 5 | Firmware networking | **Needs the board.** Talk with the Linux CLI over Ethernet, then over Wi-Fi (`esp32_hosted` via the C6; not configured yet). |
| 6 | Provisioning | **Done (ESPHome web page + `keygen --qr`); needs the board.** |
| 7 | Latency validation | **Sending half done** (§4): ~34 ms stock, ~22–27 ms with the low-latency override. The receiving half needs a speaker on the board. |
| 8 | HA integration | **Done.** Two tests in the real HA test harness: config flow, entities, monitor events, and `announce` through ffmpeg + libopus to a peer. |
| 9 | Docs for friends | **Done:** `docs/friends.md`. |

## 6. Open questions

- **I2S bus switching:** the mic and the speaker share one I2S bus (as with Mumble), so
  the speaker restarts after every talk. `speaker_hold` (3 s) keeps it running for
  replies. Measure the switch time. A full-duplex I2S setup (separate TX/RX
  channels on one port) would remove it and allow echo cancellation later.
- **Wi-Fi on the P4:** go through the C6 with `esp32_hosted`. Check broadcast and
  WMM voice priority (DSCP EF is already set on the socket).
- **Jitter target on Wi-Fi:** start at 20 ms adaptive, then check the late-packet
  statistics (`get_stats()`).
- **Key rotation:** `key_id` makes it possible. Accept two keys for a while,
  then send with the new one.
- **Receive into HA** (forward a stream to a media player): deferred. It needs
  `PLAYBACK` on HA, plus a PCM-to-HTTP bridge.
- **Echo/feedback:** while half duplex is used, an open mic near another
  device's speaker is the main risk.

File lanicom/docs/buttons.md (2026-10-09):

# Buttons, pairing and LED patterns

How the illuminated buttons on a wall box get linked to other wall boxes, and what their
LED rings show. Designed 2026-10-07, built the same day:

- protocol: [PROTOCOL.md](../spec/PROTOCOL.md) section 7 (v1.1);
- logic: `lanicom-core` `lc_buttons` (host-tested in `test/test_engine.c`);
- device: the `buttons:` option of the ESPHome component, set up in
  [`lanicom-p4.yaml`](../esphome/lanicom-p4.yaml).

## Decided

- **One button, one partner.** A link joins exactly two buttons, on two devices.
- **Buttons are the only way to call.** A device can only talk to the partners on its
  buttons. There is no "all" button.
- **Group calls:** hold two, three or four buttons at the same time to talk to all of those
  partners at once.
  - The buttons don't have to go down together. A button pressed during a talk adds its
    partner to the running stream (with a `TalkStart`).
  - Releasing a button removes its partner again. The talk ends when the last button is
    released.
- **Devices with one button exist.** The house plan:
  - kitchen and workshop, 4 buttons each;
  - one device in each child's room, with 1 button.
  - A child can only call the partner on their one button (for example the kitchen).
- **Home Assistant announcements reach any device.** Pairing is about buttons only.
- **No reset or unpair gesture on the buttons.** Kids mash buttons, so every reset and
  unpair goes through the device's web page or Home Assistant (see Reset). Buttons do
  three things: talk, group talk, pair.
- **The network key is baked in at flash time**, and can still be changed on the web
  page. Friends get a device that just works and never need to see the page.
- **Configuration beyond pairing** goes through ESPHome entities. They appear on the
  device's built-in web page (`web_server`, already enabled) and in Home Assistant.
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

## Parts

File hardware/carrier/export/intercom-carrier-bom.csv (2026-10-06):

Refs | Value | Footprint | Qty | DNP
C1 | 100nF | Capacitor_THT:C_Disc_D3.0mm_W1.6mm_P2.50mm | 1
C2 | 100nF | Capacitor_THT:C_Disc_D3.0mm_W1.6mm_P2.50mm | 1
C3 | 100nF | Capacitor_THT:C_Disc_D3.0mm_W1.6mm_P2.50mm | 1
C4 | 100nF | Capacitor_THT:C_Disc_D3.0mm_W1.6mm_P2.50mm | 1
C5 | 10uF | Capacitor_THT:CP_Radial_D5.0mm_P2.00mm | 1
J1 | P4 pins 1-20 | Connector_PinSocket_2.54mm:PinSocket_1x20_P2.54mm_Vertical | 1
J2 | Button 1 (JST-XH) | Connector_JST:JST_XH_B4B-XH-A_1x04_P2.50mm_Vertical | 1
J3 | Button 2 (JST-XH) | Connector_JST:JST_XH_B4B-XH-A_1x04_P2.50mm_Vertical | 1
J4 | Button 3 (JST-XH) | Connector_JST:JST_XH_B4B-XH-A_1x04_P2.50mm_Vertical | 1
J5 | Button 4 (JST-XH) | Connector_JST:JST_XH_B4B-XH-A_1x04_P2.50mm_Vertical | 1
J6 | Spare GPIO2/3 | Connector_PinHeader_2.54mm:PinHeader_1x04_P2.54mm_Vertical | 1
J7 | P4 pins 21-40 | Connector_PinSocket_2.54mm:PinSocket_1x20_P2.54mm_Vertical | 1
Q1 | BC547 | Package_TO_SOT_THT:TO-92_Inline | 1
Q2 | BC547 | Package_TO_SOT_THT:TO-92_Inline | 1
Q3 | BC547 | Package_TO_SOT_THT:TO-92_Inline | 1
Q4 | BC547 | Package_TO_SOT_THT:TO-92_Inline | 1
R1 | 1k | Resistor_THT:R_Axial_DIN0207_L6.3mm_D2.5mm_P7.62mm_Horizontal | 1
R2 | 1k | Resistor_THT:R_Axial_DIN0207_L6.3mm_D2.5mm_P7.62mm_Horizontal | 1
R3 | 1k | Resistor_THT:R_Axial_DIN0207_L6.3mm_D2.5mm_P7.62mm_Horizontal | 1
R4 | 1k | Resistor_THT:R_Axial_DIN0207_L6.3mm_D2.5mm_P7.62mm_Horizontal | 1
R5 | 1k | Resistor_THT:R_Axial_DIN0207_L6.3mm_D2.5mm_P7.62mm_Horizontal | 1
R6 | 1k | Resistor_THT:R_Axial_DIN0207_L6.3mm_D2.5mm_P7.62mm_Horizontal | 1
R7 | 1k | Resistor_THT:R_Axial_DIN0207_L6.3mm_D2.5mm_P7.62mm_Horizontal | 1
R8 | 1k | Resistor_THT:R_Axial_DIN0207_L6.3mm_D2.5mm_P7.62mm_Horizontal | 1
R9 | 10k | Resistor_THT:R_Axial_DIN0207_L6.3mm_D2.5mm_P7.62mm_Horizontal | 1
R10 | 10k | Resistor_THT:R_Axial_DIN0207_L6.3mm_D2.5mm_P7.62mm_Horizontal | 1
R11 | 10k | Resistor_THT:R_Axial_DIN0207_L6.3mm_D2.5mm_P7.62mm_Horizontal | 1
R12 | 10k | Resistor_THT:R_Axial_DIN0207_L6.3mm_D2.5mm_P7.62mm_Horizontal | 1
R13 | 0R | Resistor_THT:R_Axial_DIN0207_L6.3mm_D2.5mm_P7.62mm_Horizontal | 1
R14 | 0R | Resistor_THT:R_Axial_DIN0207_L6.3mm_D2.5mm_P7.62mm_Horizontal | 1
R15 | 0R | Resistor_THT:R_Axial_DIN0207_L6.3mm_D2.5mm_P7.62mm_Horizontal | 1
R16 | 0R | Resistor_THT:R_Axial_DIN0207_L6.3mm_D2.5mm_P7.62mm_Horizontal | 1

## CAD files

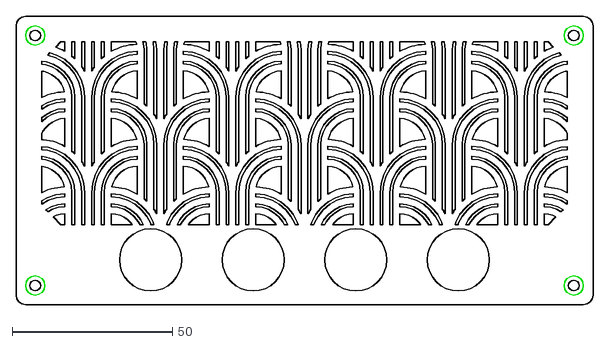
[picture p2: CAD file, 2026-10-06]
hardware/plate/front-plate-arches.dxf
180.0 x 90.0

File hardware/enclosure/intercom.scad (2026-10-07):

// Intercom enclosure, prototype for 3D printing (OpenSCAD, development snapshot).
//
//   ./render.sh                     # STLs, preview PNGs and a collision check in out/
//   openscad intercom.scad          # interactive; set `part` below or with -D part="shell"
//
// Design coordinates (mm), looking at the front: X right (0..180 = plate width), Y up
// (0..90 = plate height), Z into the wall (0 = front face of the plate). That frame is
// left-handed, the way you'd read the plate drawing and KiCad's top view. Every output
// goes through real(), which mirrors it into the right-handed frame CAD and slicers use.
// Without that mirror, the printed shell would be a mirror image of the real box (and the
// carrier's mounting holes wouldn't line up).
//
// Parts:
// - shell: open at the front; the brass plate sits in a rebate, flush with the front.
//   Inside: plate bosses (M3 heat-set inserts), carrier standoffs (M3 inserts), a closed
//   chamber behind the speaker, bottom vents, a cable opening in the back.
// - wall_plate: screws onto the in-wall box (60 mm screw spacing, horizontal or vertical).
//   The shell hooks onto its top lugs, slides down SLIDE mm, and is fixed with two M3
//   screws from below into the wall plate's tabs. The model shows the final position.
// - mic_tube: optional, glued behind a grille opening; leads sound to the P4's mic.
//
// Every number that a test print may change is a parameter below.

use <../plate/front-plate-arches.scad>  // plate_2d(), generated from the DXF by dxf2scad.py

part = "assembly";  // assembly | shell | wall_plate | mic_tube | section
                    // or a collision probe: "hit" with hit_a / hit_b (see render.sh)
hit_a = "shell";
hit_b = "speaker";
SECTION_X = 120;  // where the section preview slices (design X)

$fn = 48;
E = 0.01;  // overlap for clean boolean cuts

// --- plate (from the DXF: 180 x 90 x 3, M3 holes 6 mm from the edges) ---
PLATE_W = 180; PLATE_H = 90; PLATE_T = 3;
PLATE_R = 3;  // corner radius (from the DXF)
PLATE_HOLES = [[6, 6], [174, 6], [6, 84], [174, 84]];
BUTTONS_X = [42, 74, 106, 138]; BUTTON_Y = 14;
BUTTON_BODY_D = 19; BUTTON_BODY_L = 43;  // body plus plug, behind the plate (measure!)

// --- shell ---
WALL = 2.4;          // side walls, outside the plate edge
BACK = 3.0;          // back wall
REBATE_GAP = 0.3;    // clearance around the plate in its rebate
INNER_DEPTH = 46;    // plate back -> back wall inside; the buttons set this
OUTER_W = PLATE_W + 2 * (WALL + REBATE_GAP);
OUTER_H = PLATE_H + 2 * (WALL + REBATE_GAP);
DEPTH = PLATE_T + INNER_DEPTH + BACK;
Z_BACK = PLATE_T + INNER_DEPTH;  // inner face of the back wall
O = WALL + REBATE_GAP;           // outer edge offset from the plate edge

// Heat-set inserts (M3): hole as the insert maker recommends.
M3_INSERT_D = 4.0; M3_INSERT_L = 5.7;
M3_CLEAR_D = 3.4;
BOSS_D = 8; BOSS_L = 12;  // plate bosses reach this far behind the plate

// --- electronics: carrier board (../carrier) with the Waveshare ESP32-P4-ETH on it ---
// The carrier lies on standoffs against the back wall, components (and the P4) facing the
// plate. Seen from the front it reads like KiCad's top view: RJ45 end left, JSTs at the
// bottom (towards the buttons).
CARRIER_X0 = 86; CARRIER_Y0 = 27;  // box position of the carrier's lower left corner
CARRIER_L = 90; CARRIER_W = 48; PCB_T = 1.6;
STANDOFF_H = 5;  // through-hole leads stick out ~2 mm under the carrier
STANDOFF_D = 7;
// KiCad board coordinates (outline 100..190 x 100..148) -> box X/Y.
function carrier_xy(p) = [CARRIER_X0 + (p[0] - 100), CARRIER_Y0 + (148 - p[1])];
CARRIER_HOLES = [for (p = [[103, 103.5], [187.2, 121], [121.85, 144.3], [166.25, 144.3]]) carrier_xy(p)];
Z_CARRIER = Z_BACK - STANDOFF_H - PCB_T;  // the carrier's component side
SOCKET_H = 8.5;                          // 1x20 female sockets
Z_P4 = Z_CARRIER - SOCKET_H - PCB_T;     // the P4's component side
CARRIER_PARTS_H = 16;  // JST-XH with its plug; C5 is 11.5
// P4 STEP-model coordinates (x across 0..21, y along 0..78, RJ45 at y=0) -> box X/Y.
function p4_xy(mx, my) = [92 + my, 73 - mx];
// MIC1 is on the P4's component side (package 2.6 x 3.4 mm, centre at 4.0 / 73.25). It is
// top-port: the hole is in its lid, near the end towards the USB-C (checked on the board;
// position estimated ~0.8 mm from that end). So it hears towards the plate.
MIC_XY = p4_xy(4.0, 74.2);  // the lid's sound hole: where the mic tube points
// Where the mic tube meets the plate: the centre of a grille opening near the mic, with
// 1.3 mm of brass-free margin around the bore (found by searching the DXF). The tube is
// slanted (~7 degrees) between this point and MIC_XY. Rerun the search if the plate changes.
MIC_GRILLE_XY = [169.2, 68.6];
RJ45_H = 13.3;
POE_H = 13;          // PoE module (B) on the 6-pin header: socket ~9 mm, then its PCB and parts
POE_Y = [20, 52];    // along the P4
POE_W = 26;          // slightly wider than the P4
RJ45_PLUG_L = 22;    // plug plus the cable's bend, in front of the jack

// --- speaker: 40 x 40 x 18, in a closed chamber ---
SPK = 40; SPK_H = 18;
SPK_CENTER = [40, 54];
CHAMBER_WALL = 2;
SPK_WIRE_SLOT = [4, 3];  // notch for the speaker wires: width, height (seal it after fitting)

// --- cable and wall plate ---
CABLE_HOLE = [65, 35, 84, 72];  // x0, y0, x1, y1 in the back wall, beside the RJ45 jack
WP_T = 3;
WP_MARGIN = 3;                  // wall plate is this much smaller than the plate
WALLBOX_CENTER = [74, 53];      // in-wall box centre behind the shell (adjust to taste)
WALLBOX_SCREWS = 60;
WALLBOX_SLOT = [10, 4.2];       // slot length, width
SCREW_HEAD = [9, 2.2];          // wall box screw heads: diameter, height
SLIDE = 5;                      // the shell is hung on, then slid down this far
HOOK_X = [100, 160]; HOOK_Y = 80;  // top hooks, above the carrier
TAB_X = [58, 122];              // bottom tabs + screws: in the gaps between the buttons
TAB_Z = Z_BACK - 5;             // height of the fixing screws

// --- vents (bottom face) ---
VENT_L = 30; VENT_W = 2.5; VENT_PITCH = 6;
VENT_X = [86, 176];  // below the carrier

// ---------------------------------------------------------------------------

module box(x, y, z, dx, dy, dz) { translate([x, y, z]) cube([dx, dy, dz]); }

// The plate's outline, grown by `grow` all round (corners stay concentric).
module plate_outline(grow = 0) {
  offset(r = grow) hull() for (x = [PLATE_R, PLATE_W - PLATE_R], y = [PLATE_R, PLATE_H - PLATE_R])
    translate([x, y]) circle(r = PLATE_R);
}

// A hole along +Y (through the bottom wall), centred on x/z.
module y_hole(x, y0, y1, z, d) {
  translate([x, y0, z]) rotate([-90, 0, 0]) cylinder(d = d, h = y1 - y0);
}

module shell_body() {
  difference() {
    // Outside: the plate's outline grown by the gap and the wall, so the corners are rounded
    // too (radius PLATE_R + O) and the wall is equally thick all round.
    linear_extrude(DEPTH) plate_outline(O);
    // Hollow from the front, leaving the back wall; the plate sits in the opening, whose
    // corners follow the plate's rounded ones with the same gap.
    translate([0, 0, -E]) linear_extrude(Z_BACK + E) plate_outline(REBATE_GAP);
  }
  // Plate bosses, joined to the corner walls (not to the back wall).
  for (p = PLATE_HOLES) {
    cx = p[0] < PLATE_W / 2 ? -REBATE_GAP : PLATE_W + REBATE_GAP;
    cy = p[1] < PLATE_H / 2 ? -REBATE_GAP : PLATE_H + REBATE_GAP;
    translate([p[0], p[1], PLATE_T]) cylinder(d = BOSS_D, h = BOSS_L);
    box(min(p[0], cx), min(p[1], cy), PLATE_T, abs(cx - p[0]), abs(cy - p[1]), BOSS_L);
  }
  // Carrier standoffs on the back wall.
  for (p = CARRIER_HOLES)
    translate([p[0], p[1], Z_BACK - STANDOFF_H]) cylinder(d = STANDOFF_D, h = STANDOFF_H + E);
  // Speaker chamber: walls from the back wall to the plate; the speaker sits at the front.
  outer = SPK + 2 * CHAMBER_WALL + 1;
  translate([SPK_CENTER[0], SPK_CENTER[1], PLATE_T + 0.5]) difference() {
    translate([-outer / 2, -outer / 2, 0]) cube([outer, outer, INNER_DEPTH - 0.5 + E]);
    translate([-(SPK + 1) / 2, -(SPK + 1) / 2, -E]) cube([SPK + 1, SPK + 1, INNER_DEPTH]);
  }
  // Ledge that holds the speaker against the plate (18 mm speaker behind 0.5 mm of foam).
  translate([SPK_CENTER[0], SPK_CENTER[1], PLATE_T + SPK_H + 0.5]) difference() {
    translate([-(SPK + 1) / 2, -(SPK + 1) / 2, 0]) cube([SPK + 1, SPK + 1, 2]);
    translate([-(SPK - 6) / 2, -(SPK - 6) / 2, -E]) cube([SPK - 6, SPK - 6, 2 + 2 * E]);
  }
}
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

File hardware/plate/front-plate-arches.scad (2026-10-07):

// Generated from front-plate-arches.dxf by dxf2scad.py; do not edit.
// 140 holes. The DXF is the source for the laser cutter.
module plate_2d() {
  difference() {
    polygon([[3.000,0.000],[177.000,0.000],[177.314,0.016],[177.624,0.066],[177.927,0.147],[178.220,0.259],[178.500,0.402],[178.763,0.573],[179.007,0.771],[179.229,0.993],[179.427,1.237],[179.598,1.500],[179.741,1.780],[179.853,2.073],[179.934,2.376],[179.984,2.686],[180.000,3.000],[180.000,87.000],[179.984,87.314],[179.934,87.624],[179.853,87.927],[179.741,88.220],[179.598,88.500],[179.427,88.763],[179.229,89.007],[179.007,89.229],[178.763,89.427],[178.500,89.598],[178.220,89.741],[177.927,89.853],[177.624,89.934],[177.314,89.984],[177.000,90.000],[3.000,90.000],[2.686,89.984],[2.376,89.934],[2.073,89.853],[1.780,89.741],[1.500,89.598],[1.237,89.427],[0.993,89.229],[0.771,89.007],[0.573,88.763],[0.402,88.500],[0.259,88.220],[0.147,87.927],[0.066,87.624],[0.016,87.314],[0.000,87.000],[0.000,3.000],[0.016,2.686],[0.066,2.376],[0.147,2.073],[0.259,1.780],[0.402,1.500],[0.573,1.237],[0.771,0.993],[0.993,0.771],[1.237,0.573],[1.500,0.402],[1.780,0.259],[2.073,0.147],[2.376,0.066],[2.686,0.016],[3.000,0.000]]);
    polygon([[150.282,82.000],[150.282,79.024],[149.391,79.504],[148.470,79.929],[147.520,80.298],[146.543,80.609],[145.541,80.861],[144.516,81.053],[143.470,81.178],[142.404,81.236],[142.637,82.000]]);
    polygon([[166.000,82.000],[167.649,80.352],[167.480,80.298],[166.530,79.929],[165.609,79.504],[164.718,79.024],[164.718,82.000]]);
    polygon([[159.485,82.000],[159.485,74.260],[159.365,74.088],[159.246,73.913],[159.130,73.741],[159.016,73.563],[158.905,73.385],[158.796,73.208],[158.688,73.027],[158.583,72.844],[158.583,82.000]]);
    polygon([[156.417,82.000],[156.417,72.844],[156.312,73.027],[156.204,73.208],[156.095,73.385],[155.984,73.563],[155.870,73.741],[155.754,73.913],[155.635,74.088],[155.515,74.260],[155.515,82.000]]);
    polygon([[153.350,82.000],[153.350,76.742],[153.239,76.842],[153.128,76.944],[153.017,77.044],[152.906,77.144],[152.792,77.244],[152.678,77.341],[152.561,77.439],[152.445,77.533],[152.445,82.000]]);
    polygon([[162.555,82.000],[162.555,77.533],[162.439,77.439],[162.322,77.341],[162.208,77.244],[162.094,77.144],[161.983,77.044],[161.872,76.944],[161.761,76.842],[161.650,76.742],[161.650,82.000]]);
    polygon([[172.000,64.616],[171.891,64.674],[170.970,65.099],[170.020,65.468],[169.043,65.779],[168.041,66.032],[167.016,66.223],[165.970,66.348],[164.904,66.407],[165.309,67.736],[165.923,68.961],[166.722,70.057],[167.685,71.009],[168.796,71.795],[170.028,72.392],[171.364,72.781],[172.000,72.852]]);
    polygon([[105.282,82.000],[105.282,79.024],[104.391,79.504],[103.469,79.929],[102.520,80.298],[101.543,80.609],[100.541,80.861],[99.516,81.053],[98.470,81.178],[97.404,81.236],[97.637,82.000]]);
    polygon([[127.363,82.000],[127.596,81.236],[126.530,81.178],[125.484,81.053],[124.459,80.861],[123.457,80.609],[122.480,80.298],[121.531,79.929],[120.609,79.504],[119.718,79.024],[119.718,82.000]]);
    polygon([[114.485,82.000],[114.485,74.260],[114.365,74.088],[114.246,73.913],[114.129,73.741],[114.016,73.563],[113.905,73.385],[113.796,73.208],[113.688,73.027],[113.583,72.844],[113.583,82.000]]);
    polygon([[111.417,82.000],[111.417,72.844],[111.312,73.027],[111.204,73.208],[111.095,73.385],[110.984,73.563],[110.871,73.741],[110.754,73.913],[110.635,74.088],[110.515,74.260],[110.515,82.000]]);
    polygon([[108.350,82.000],[108.350,76.742],[108.239,76.842],[108.128,76.944],[108.017,77.044],[107.906,77.144],[107.792,77.244],[107.678,77.341],[107.561,77.439],[107.445,77.533],[107.445,82.000]]);
    polygon([[117.555,82.000],[117.555,77.533],[117.439,77.439],[117.322,77.341],[117.208,77.244],[117.094,77.144],[116.983,77.044],[116.872,76.944],[116.761,76.842],[116.650,76.742],[116.650,82.000]]);
    polygon([[127.782,64.194],[126.891,64.674],[125.969,65.099],[125.020,65.468],[124.043,65.779],[123.041,66.032],[122.016,66.223],[120.970,66.348],[119.904,66.407],[120.309,67.736],[120.923,68.961],[121.722,70.057],[122.685,71.009],[123.796,71.795],[125.028,72.392],[126.364,72.781],[127.782,72.939]]);
    polygon([[150.096,66.407],[149.030,66.348],[147.984,66.223],[146.959,66.032],[145.957,65.779],[144.980,65.468],[144.030,65.099],[143.109,64.674],[142.218,64.194],[142.218,72.939],[143.636,72.781],[144.972,72.392],[146.204,71.795],[147.315,71.009],[148.278,70.057],[149.077,68.961],[149.691,67.736]]);
    polygon([[136.985,59.430],[136.865,59.258],[136.746,59.083],[136.630,58.911],[136.516,58.734],[136.405,58.556],[136.296,58.378],[136.188,58.198],[136.083,58.015],[136.083,79.499],[136.334,82.000],[137.238,82.000],[136.985,79.499]]);
    polygon([[133.917,58.015],[133.812,58.198],[133.704,58.378],[133.595,58.556],[133.484,58.734],[133.370,58.911],[133.254,59.083],[133.135,59.258],[133.015,59.430],[133.015,79.499],[132.762,82.000],[133.666,82.000],[133.917,79.499]]);
    polygon([[130.850,61.912],[130.739,62.012],[130.628,62.115],[130.517,62.215],[130.406,62.315],[130.292,62.415],[130.178,62.512],[130.061,62.609],[129.945,62.703],[129.945,79.499],[129.739,81.575],[129.608,82.000],[130.550,82.000],[130.625,81.755],[130.850,79.499]]);
    polygon([[140.055,62.703],[139.939,62.609],[139.822,62.512],[139.708,62.415],[139.594,62.315],[139.483,62.215],[139.372,62.115],[139.261,62.012],[139.150,61.912],[139.150,79.499],[139.375,81.755],[139.450,82.000],[140.392,82.000],[140.261,81.575],[140.055,79.499]]);
    polygon([[150.282,49.365],[149.391,49.845],[148.470,50.270],[147.520,50.639],[146.543,50.950],[145.541,51.202],[144.516,51.394],[143.470,51.519],[142.404,51.577],[142.809,52.907],[143.423,54.131],[144.222,55.228],[145.185,56.180],[146.296,56.965],[147.528,57.562],[148.864,57.951],[150.282,58.109]]);
    polygon([[172.000,51.545],[171.530,51.519],[170.484,51.394],[169.459,51.202],[168.457,50.950],[167.480,50.639],[166.530,50.270],[165.609,49.845],[164.718,49.365],[164.718,58.109],[166.136,57.951],[167.472,57.562],[168.704,56.965],[169.815,56.180],[170.778,55.228],[171.577,54.131],[172.000,53.288]]);
    polygon([[159.485,44.601],[159.365,44.429],[159.246,44.254],[159.130,44.082],[159.016,43.904],[158.905,43.727],[158.796,43.549],[158.688,43.368],[158.583,43.185],[158.583,64.669],[158.871,67.545],[159.696,70.227],[161.006,72.659],[162.738,74.782],[164.840,76.545],[167.252,77.883],[169.416,78.584],[170.135,77.865],[170.101,77.861],[167.602,77.053],[165.345,75.796],[163.377,74.144],[161.756,72.153],[160.529,69.874],[159.757,67.362],[159.485,64.669]]);
    polygon([[156.417,43.185],[156.312,43.368],[156.204,43.549],[156.095,43.727],[155.984,43.904],[155.870,44.082],[155.754,44.254],[155.635,44.429],[155.515,44.601],[155.515,64.669],[155.243,67.362],[154.471,69.874],[153.244,72.153],[151.623,74.144],[149.655,75.796],[147.398,77.053],[144.899,77.861],[142.218,78.172],[142.218,79.077],[145.083,78.746],[147.748,77.883],[150.160,76.545],[152.262,74.782],[153.994,72.659],[155.304,70.227],[156.129,67.545],[156.417,64.669]]);
    polygon([[153.350,47.083],[153.239,47.183],[153.128,47.285],[153.017,47.385],[152.906,47.485],[152.792,47.585],[152.678,47.682],[152.561,47.779],[152.445,47.874],[152.445,64.669],[152.239,66.746],[151.643,68.683],[150.701,70.441],[149.455,71.976],[147.942,73.253],[146.204,74.224],[144.283,74.857],[142.218,75.104],[142.218,76.009],[144.464,75.743],[146.554,75.057],[148.447,73.999],[150.094,72.614],[151.451,70.943],[152.475,69.033],[153.125,66.926],[153.350,64.669]]);
    polygon([[162.555,47.874],[162.439,47.779],[162.322,47.682],[162.208,47.585],[162.094,47.485],[161.983,47.385],[161.872,47.285],[161.761,47.183],[161.650,47.083],[161.650,64.669],[161.875,66.926],[162.525,69.033],[163.549,70.943],[164.906,72.614],[166.553,73.999],[168.446,75.057],[170.536,75.743],[172.000,75.916],[172.000,75.011],[170.717,74.857],[168.796,74.224],[167.058,73.253],[165.545,71.976],[164.299,70.441],[163.357,68.683],[162.761,66.746],[162.555,64.669]]);
    polygon([[172.000,34.957],[171.891,35.016],[170.970,35.440],[170.020,35.809],[169.043,36.120],[168.041,36.373],[167.016,36.565],[165.970,36.690],[164.904,36.748],[165.309,38.078],[165.923,39.302],[166.722,40.398],[167.685,41.350],[168.796,42.136],[170.028,42.733],[171.364,43.122],[172.000,43.193]]);
    polygon([[172.000,61.052],[169.898,62.224],[167.399,63.032],[164.718,63.342],[164.718,64.247],[167.583,63.917],[170.248,63.054],[172.000,62.082]]);
    polygon([[172.000,57.091],[171.955,57.146],[170.442,58.423],[168.704,59.395],[166.783,60.028],[164.718,60.275],[164.718,61.180],[166.964,60.913],[169.054,60.228],[170.947,59.170],[172.000,58.284]]);
    polygon([[60.282,82.000],[60.282,79.024],[59.391,79.504],[58.469,79.929],[57.520,80.298],[56.543,80.609],[55.541,80.861],[54.516,81.053],[53.470,81.178],[52.404,81.236],[52.637,82.000]]);
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

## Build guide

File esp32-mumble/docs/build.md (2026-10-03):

# Build and Flash

## Prerequisites

- [ESPHome](https://esphome.io/) **2026.7.0+** (this repo pins **2026.7.1** in `requirements.txt`)
- Python **3.12+**
- One of the supported ESP32-S3 boards

**Before compiling**: Create `esphome/secrets.yaml` from `secrets.example.yaml` with `wifi_ssid` and `wifi_password`. The board configs reference these via `!secret`. API encryption and OTA password are optional (see comments in the board YAMLs and `secrets.example.yaml`).

### Installing ESPHome

```bash
pip install -r requirements.txt
```

On macOS you can also use Homebrew (`brew install esphome`), then ensure the CLI is at least 2026.7.0 (`esphome version`).

Or use the [ESPHome Dashboard](https://web.esphome.io/) for a browser-based workflow.

## Build

From the project root:

```bash
esphome compile esphome/generic-esp32s3.yaml
```

Or use the build script:

```bash
./scripts/build.sh generic    # generic ESP32-S3 (Arduino)
./scripts/build.sh box        # ESP32-S3 Box (ESP-IDF, lwIP netconn, requires 2026.7.0+)
./scripts/build.sh box3       # ESP32-S3 Box 3 (ESP-IDF, lwIP netconn)
./scripts/build.sh echo       # M5Stack Atom Echo (Arduino)
./scripts/build.sh voice-pe   # Home Assistant Voice PE (ESP-IDF, lwIP netconn)
./scripts/build.sh all        # all configs
```

Or via Makefile:

```bash
make build                    # default: generic
make CONFIG=box build         # ESP32-S3 Box (ESP-IDF)
make CONFIG=box3 build        # ESP32-S3 Box 3 (ESP-IDF)
make CONFIG=voice-pe build    # Home Assistant Voice PE (ESP-IDF)
make all
```

## Flash

Connect the device via USB, then:

```bash
esphome run esphome/generic-esp32s3.yaml --device /dev/ttyUSB0
```

Or:

```bash
./scripts/flash.sh generic --device /dev/ttyUSB0
make flash PORT=/dev/ttyUSB0
```

On macOS the port is typically `/dev/cu.usbmodem*`.

## Configuration

- **Secrets** (required before compile): Add `esphome/secrets.yaml` with Wi‑Fi credentials (see `secrets.example.yaml`). Optionally enable HA API encryption and/or an OTA password by uncommenting those secrets and wiring them in your board YAML.
- **Mumble TLS**: By default the client skips server certificate verification (trusted LAN). Set the Mumble component `ca_cert` option to a PEM CA to enable verification.
- **Mumble**: Server, port, username, password, channel, mode (always-on / push-to-talk), and crypto (default: **Legacy**; or **Lite** for trusted LAN) are exposed as config entities. **Server** defaults to empty and is auto-detected from the Home Assistant server IP when the device is adopted by HA (e.g. for go-mumble-server addon); set it manually in YAML or in HA to override. Username defaults to `esp32-<MAC>`. Channel defaults to **Root**. Changing server, username, password, channel, or crypto forces a reconnect. **Speaker Volume** controls output and persists across reboots; microphone is controlled via physical button wiring. On Box/Box-3, **Speaker Power** toggles the hardware amplifier (GPIO46); on Voice PE it is GPIO47. Voice PE also maps the jog wheel to volume, the mute slider to Mute, and the center button to PTT/Communicator. Diagnostics include WiFi signal, Mumble connected, ping, and **Reset Config**. **Voice Received** appears under Sensors. All values persist in NVS and are restored on boot.

## Dependencies

- **Opus**: The Mumble component uses a **local vendored Opus library** (`lib/micro-opus/`) based on [esphome-libs/micro-opus](https://github.com/esphome-libs/micro-opus) v0.4.1. It uses heap-based pseudostack allocation (PSRAM when available) and Xtensa DSP optimizations. Do not remove or modify `lib/micro-opus/` — it is required for compilation.
- **ESP32-S3 Box / Box-3 / Voice PE (ESP-IDF)**: These boards use `framework: type: esp-idf` with lwIP netconn for UDP. First flash must be via USB, not OTA. Voice PE also vendors `components/voice_kit/` for the XMOS mic DSP (may DFU firmware on first boot).
- **Toolchain**: All board configs set `esp32.toolchain: platformio`. ESPHome 2026.7 defaults to the native ESP-IDF toolchain, which does not support this project's local `symlink://` micro-opus library or the mbedtls PlatformIO pre-script.

## Troubleshooting

- **Component not found**: Ensure `external_components` points to `../components` relative to the YAML file (configs are in `esphome/`).
- **Board not found**: Use `esphome boards` to list available boards. For Box 3 use `esp32s3box3`; for original Box use `esp32s3box`.
- **Compilation errors**: Ensure you have the correct ESPHome version (`esphome version` should be 2026.7.0+; `pip install -r requirements.txt` pins 2026.7.1). If Opus-related errors occur, verify `lib/micro-opus/` exists and is complete (no missing files).
- **UDP ping timeout**: Box and Box-3 (ESP-IDF netconn) support UDP. If ping stays "nan" and voice uses TCP tunnel, check firewall/NAT.
- **"UDP ping echo not received"**: On same-LAN setups this was historically caused by an OCB2 encryption mismatch; the implementation now matches grumble. If it persists, check NAT/firewall rules or try Lite crypto mode (cleartext UDP) to isolate networking vs. encryption.

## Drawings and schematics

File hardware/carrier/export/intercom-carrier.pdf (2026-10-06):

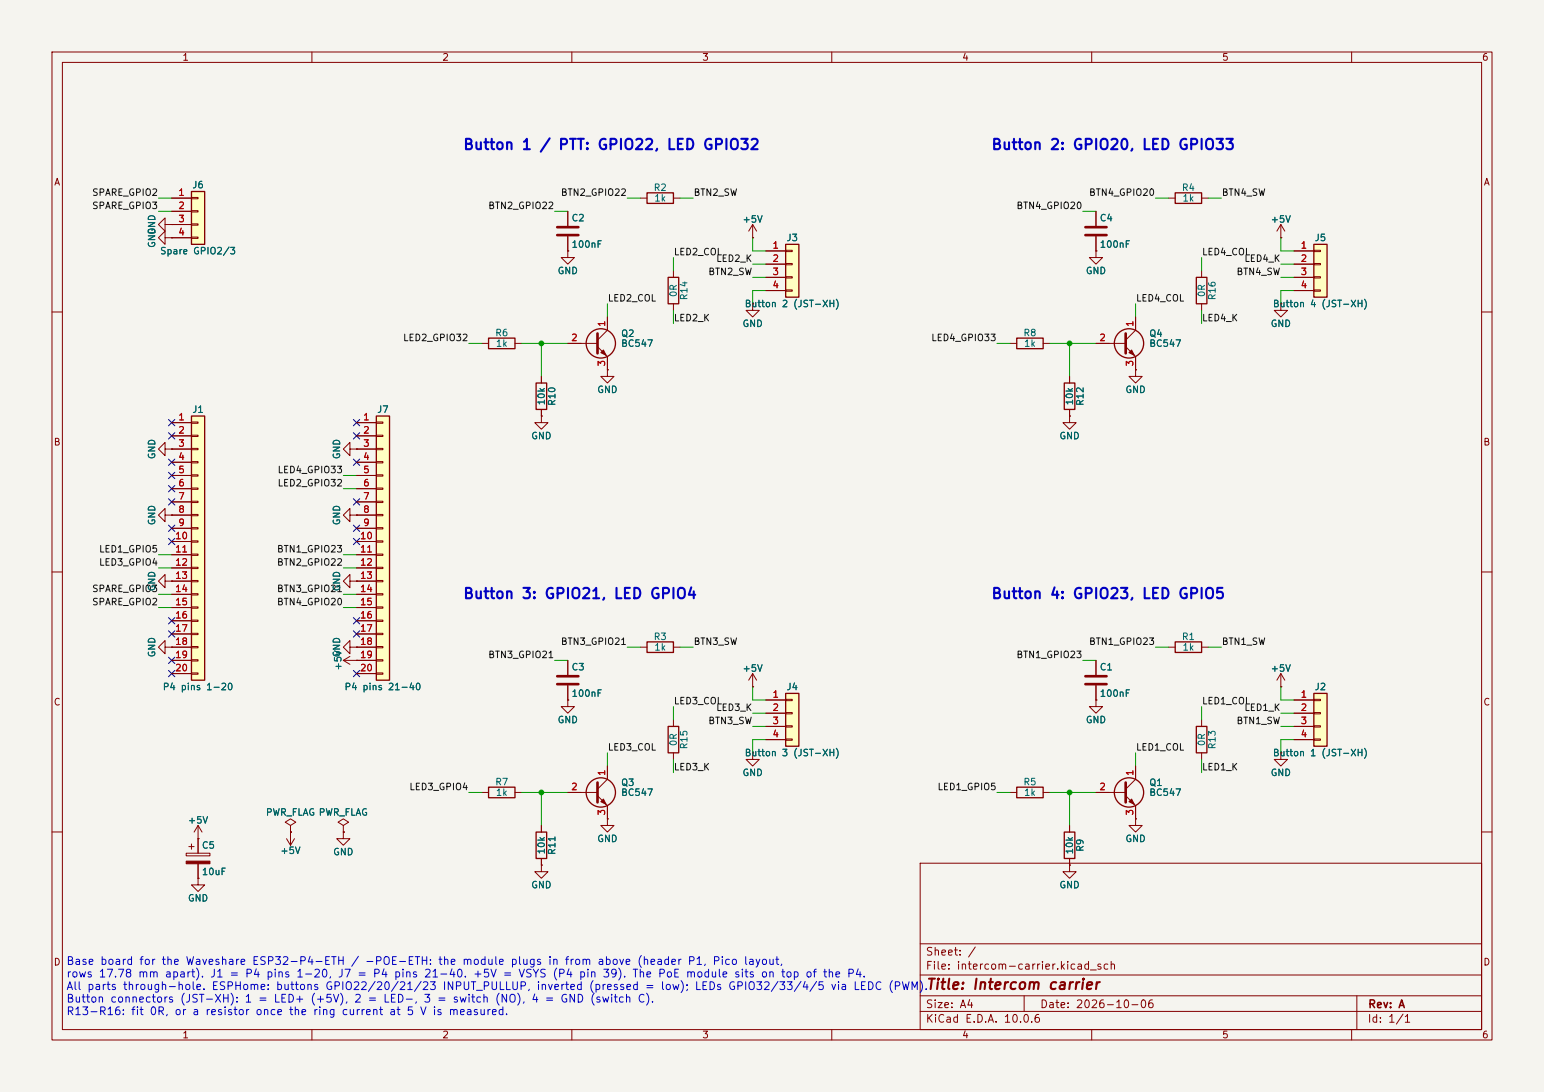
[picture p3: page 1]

4 GND GND GND GND GND

1k GND GND GND GND

J3 Button 2 (JST-XH) 10k R10 GND

J5 Button 4 (JST-XH) GND

Base board for the Waveshare ESP32-P4-ETH / -POE-ETH: the module plugs in from above (header P1, Pico layout, rows 17.78 mm apart). J1 = P4 pins 1-20, J7 = P4 pins 21-40. +5V = VSYS (P4 pin 39). The PoE module sits on top of the P4.

All parts through-hole. ESPHome: buttons GPIO22/20/21/23 INPUT_PULLUP, inverted (pressed = low); LEDs GPIO32/33/4/5 via LEDC (PWM).
Button connectors (JST-XH): 1 = LED+ (+5V), 2 = LED-, 3 = switch (NO), 4 = GND (switch C).
R13-R16: fit 0R, or a resistor once the ring current at 5 V is measured.

Size: A4 | Rev: A
KiCad E.D.A. 10.0.6 | Id: 1/1

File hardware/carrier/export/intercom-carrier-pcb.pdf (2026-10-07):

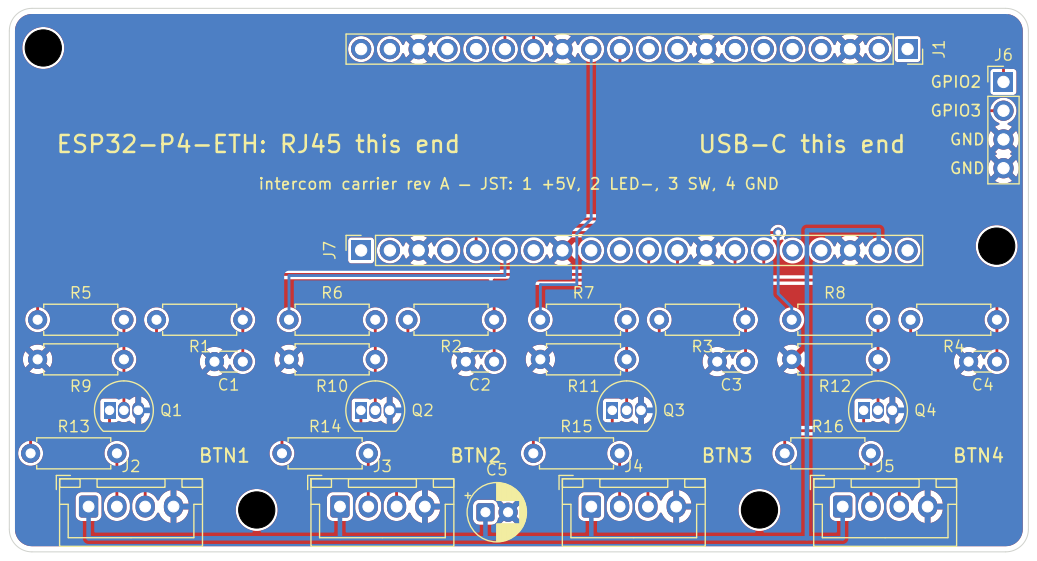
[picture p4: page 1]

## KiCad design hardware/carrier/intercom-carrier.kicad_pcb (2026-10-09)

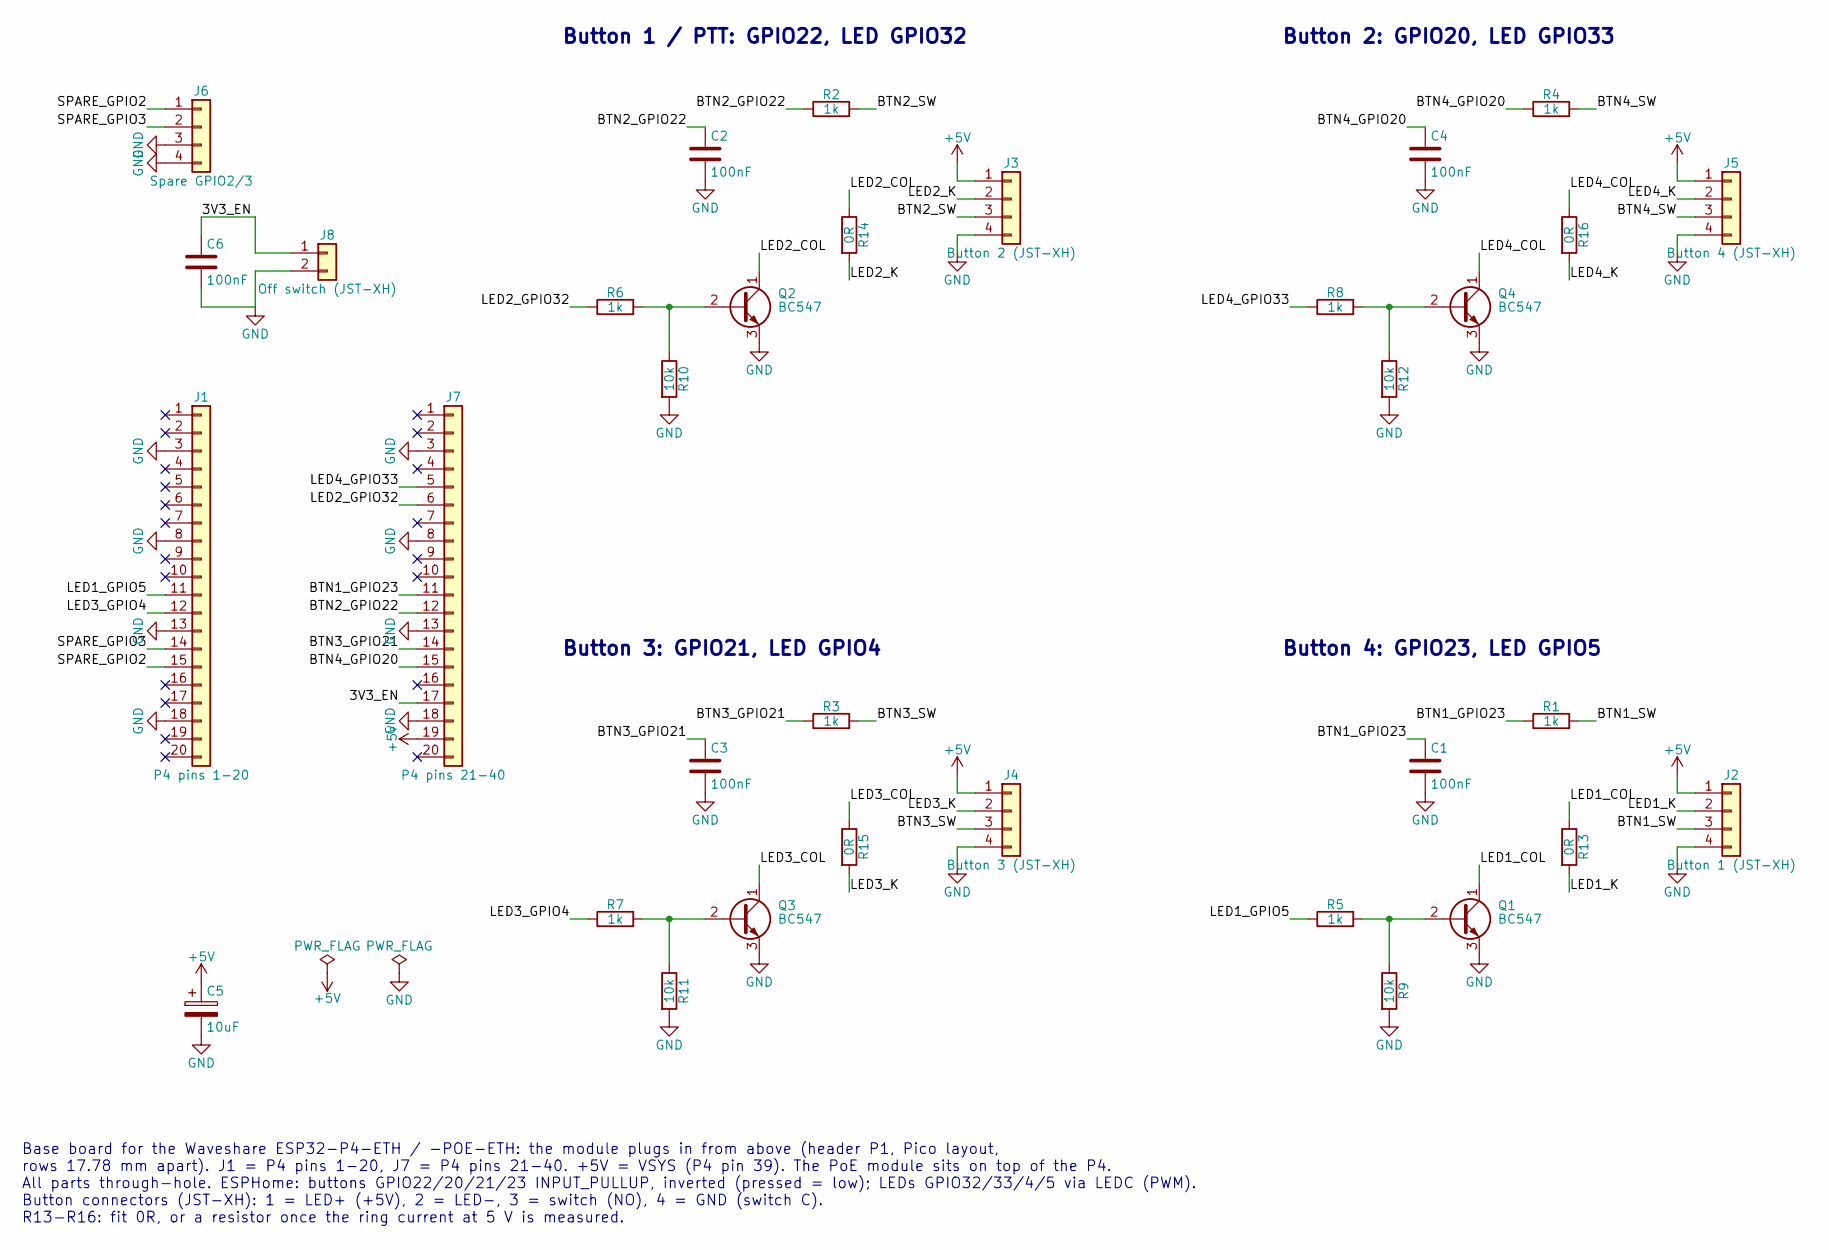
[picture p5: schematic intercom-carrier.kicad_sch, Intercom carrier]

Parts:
C1, C2, C3, C4, C6: 100nF; C_Disc_D3.0mm_W1.6mm_P2.50mm
C5: 10uF; CP_Radial_D5.0mm_P2.00mm
J1: P4 pins 1-20; PinSocket_1x20_P2.54mm_Vertical
J2: Button 1 (JST-XH); JST_XH_B4B-XH-A_1x04_P2.50mm_Vertical
J3: Button 2 (JST-XH); JST_XH_B4B-XH-A_1x04_P2.50mm_Vertical
J4: Button 3 (JST-XH); JST_XH_B4B-XH-A_1x04_P2.50mm_Vertical
J5: Button 4 (JST-XH); JST_XH_B4B-XH-A_1x04_P2.50mm_Vertical
J6: Spare GPIO2/3; PinHeader_1x04_P2.54mm_Vertical
J7: P4 pins 21-40; PinSocket_1x20_P2.54mm_Vertical
J8: Off switch (JST-XH); JST_XH_B2B-XH-A_1x02_P2.50mm_Vertical
Q1, Q2, Q3, Q4: BC547; TO-92_Inline
R1, R2, R3, R4, R5, R6, R7, R8: 1k; R_Axial_DIN0207_L6.3mm_D2.5mm_P7.62mm_Horizontal
R9, R10, R11, R12: 10k; R_Axial_DIN0207_L6.3mm_D2.5mm_P7.62mm_Horizontal
R13, R14, R15, R16: 0R; R_Axial_DIN0207_L6.3mm_D2.5mm_P7.62mm_Horizontal

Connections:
+5V: C5.1, J2.1, J3.1, J4.1, J5.1, J7.19
/3V3_EN: C6.1, J7.17, J8.1
/BTN1_GPIO23: C1.1, J7.11, R1.1
/BTN1_SW: J2.3, R1.2
/BTN2_GPIO22: C2.1, J7.12, R2.1
/BTN2_SW: J3.3, R2.2
/BTN3_GPIO21: C3.1, J7.14, R3.1
/BTN3_SW: J4.3, R3.2
/BTN4_GPIO20: C4.1, J7.15, R4.1
/BTN4_SW: J5.3, R4.2
/LED1_COL: Q1.1 (C), R13.1
/LED1_GPIO5: J1.11, R5.1
/LED1_K: J2.2, R13.2
/LED2_COL: Q2.1 (C), R14.1
/LED2_GPIO32: J7.6, R6.1
/LED2_K: J3.2, R14.2
/LED3_COL: Q3.1 (C), R15.1
/LED3_GPIO4: J1.12, R7.1
/LED3_K: J4.2, R15.2
/LED4_COL: Q4.1 (C), R16.1
/LED4_GPIO33: J7.5, R8.1
/LED4_K: J5.2, R16.2
/SPARE_GPIO2: J1.15, J6.1
/SPARE_GPIO3: J1.14, J6.2
GND: C1.2, C2.2, C3.2, C4.2, C5.2, C6.2, J1.3, J1.8, J1.13, J1.18, J2.4, J3.4, J4.4, J5.4, J6.3, J6.4, J7.3, J7.8, J7.13, J7.18, J8.2, Q1.3 (E), Q2.3 (E), Q3.3 (E), Q4.3 (E), R9.2, R10.2, R11.2, R12.2
unnamed: Q1.2 (B), R5.2, R9.1
unnamed: Q2.2 (B), R6.2, R10.1
unnamed: Q3.2 (B), R7.2, R11.1
unnamed: Q4.2 (B), R8.2, R12.1

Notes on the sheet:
Button 1 / PTT: GPIO22, LED GPIO32
Button 3: GPIO21, LED GPIO4
Button 2: GPIO20, LED GPIO33
Button 4: GPIO23, LED GPIO5
Base board for the Waveshare ESP32-P4-ETH / -POE-ETH: the module plugs in from above (header P1, Pico layout, rows 17.78 mm apart). J1 = P4 pins 1-20, J7 = P4 pins 21-40. +5V = VSYS (P4 pin 39). The PoE module sits on top of the P4. All parts through-hole. ESPHome: buttons GPIO22/20/21/23 INPUT_PUL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

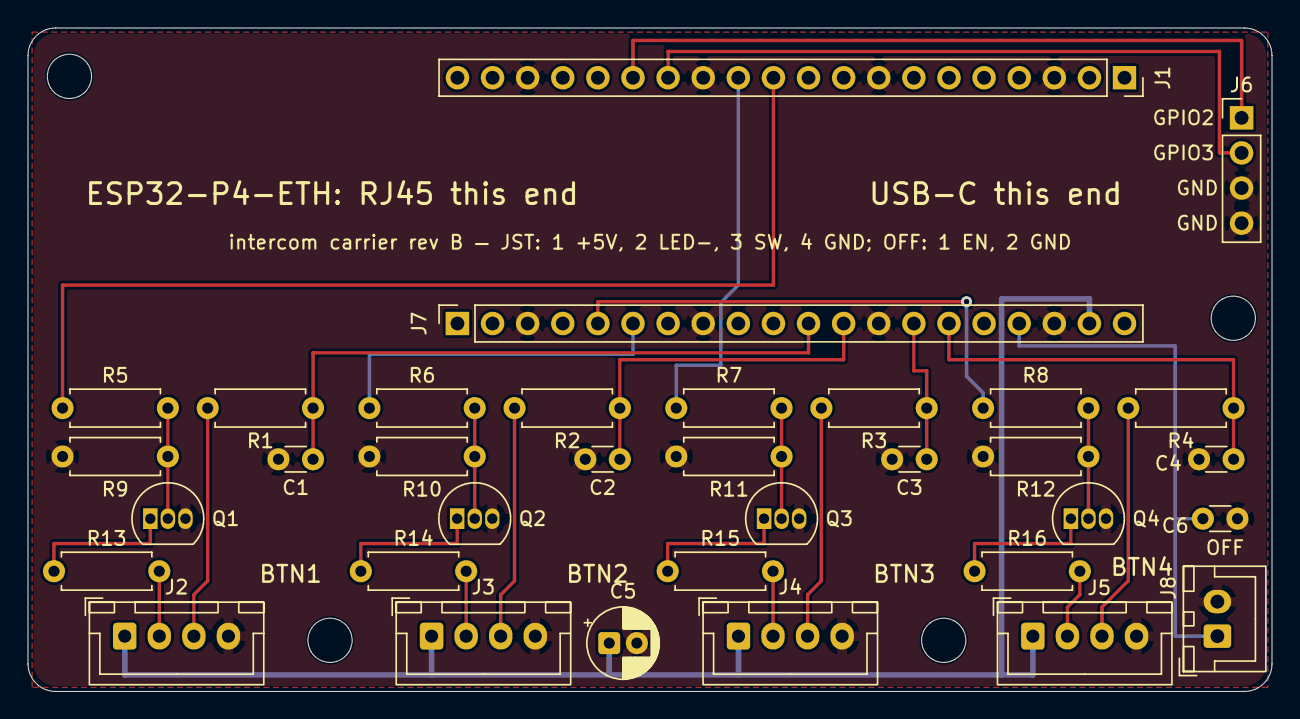
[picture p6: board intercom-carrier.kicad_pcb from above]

Board: 2 copper layers, 90.0 x 48.0 mm, 38 parts (0 on the bottom side), 29 nets.

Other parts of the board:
H1, H2, H3, H4: MountingHole_3.2mm_M3

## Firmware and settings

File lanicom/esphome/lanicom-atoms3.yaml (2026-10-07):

# lanicom on an M5Stack AtomS3 Lite with the Atomic Audio-3.5 Base: a one-button intercom.
#
# DOES NOT WORK (2026-10-07). The AtomS3 Lite has no PSRAM: Wi-Fi, the web server and Opus
# (encoder 31.6 KB, decoders 18.4 KB each, a 60 KB scratch area) don't fit in 512 KB of
# on-chip RAM. Pairing worked; receiving didn't crash but played nothing; talking crashed in
# the encoder every time. Use a board with PSRAM (AtomS3R, XIAO ESP32S3, the P4) instead.
# The pins, the base's I/O expander and the codec setup below are right for the base
# (proven on a XIAO ESP32S3: lanicom-xiao.yaml).
#
# The top button is the box's one button: hold it 5 s to pair it with a button on another box
# (docs/buttons.md), then hold it to talk to that partner. The RGB LED is its ring.
#
# Base: ES8311 codec, analog MEMS mic (keep the base's mic switch on ON), NS4150B amp, enabled
# through a PI4IOE5V6408 expander. The base has no MCLK line; the codec runs from the bit clock,
# which needs M5Stack's es8311 fork (ESPHome's own one only hisses).
#
# First: secrets.yaml needs wifi_ssid and wifi_password next to the other secrets.
# First flash over USB-C:   esphome run lanicom-atoms3.yaml
# Then open http://<device>.local/ (user admin) and paste the network key, or bake it in with
#                           esphome -s network_key 'xxxxx-...' run lanicom-atoms3.yaml

substitutions:
  name: lanicom-atom
  friendly_name: Intercom Atom
  network_key: ""

esphome:
  name: ${name}
  friendly_name: ${friendly_name}
  name_add_mac_suffix: true
  min_version: "2026.7.0"
  on_boot:
    - priority: -100
      then:
        # ES8311 mic gain, straight to the codec (as on the P4).
        - lambda: |-
            id(es8311_dac).write_byte(0x14, 0x10 | (uint8_t)(id(mic_pga).state / 3));
            id(es8311_dac).write_byte(0x16, (uint8_t)(id(mic_digital).state / 6));
        - speaker.volume_set:
            id: atom_speaker
            volume: !lambda 'return id(speaker_volume).state / 100.0f;'
        - lambda: |-
            id(intercom).set_ring_brightness(0, id(ring_1_brightness).state / 100.0f);
            id(intercom).set_night_brightness(id(night_brightness).state / 100.0f);
            id(intercom).set_night_hours((int) id(night_start).state, (int) id(night_end).state);

esp32:
  board: esp32-s3-devkitc-1
  flash_size: 8MB
  framework:
    type: esp-idf
    advanced:
      compiler_optimization: SIZE
    sdkconfig_options:
      # No PSRAM here: Opus's default 120 KB scratch per thread can't be allocated, and the
      # first encode/decode then crashes. Only lanicom's audio task uses Opus, so one shared
      # scratch area of the minimum size, in internal RAM, is enough.
      CONFIG_OPUS_NONTHREADSAFE_PSEUDOSTACK: y
      CONFIG_OPUS_PSEUDOSTACK_SIZE: "60000"
      CONFIG_OPUS_PSEUDOSTACK_INTERNAL_ONLY: y

wifi:
  ssid: !secret wifi_ssid
  password: !secret wifi_password
  power_save_mode: none  # voice: no 100 ms sleeps between beacons
  # No fallback hotspot / captive portal: RAM is too tight without PSRAM.

logger:
  hardware_uart: USB_SERIAL_JTAG

api:
  reboot_timeout: 0s
  encryption:
    key: !secret api_encryption_key

ota:
  - platform: esphome
    password: !secret ota_password
  - platform: web_server

web_server:
  port: 80
  version: 3
  auth:
    type: digest
    username: admin
    password: !secret web_password

factory_reset:
  resets_required: 5
  max_delay: 10s
  on_increment:
    - lambda: 'id(intercom).identify(300);'

time:
  - platform: sntp
    id: sntp_clock
    timezone: Europe/Amsterdam

mdns:
  services:
    - service: "_lanicom"
      protocol: "_udp"
      port: 47100
      txt:
        v: "1"

external_components:
  - source:
      type: local
      path: components
  # ESPHome's own es8311 mis-sets the clock multiplier when the codec runs from the bit
  # clock (no MCLK line): the speaker only hisses. M5Stack's fork gets it right.
  - source: github://m5stack/esphome-yaml@cc708ddcc9dea7cfc746b408d2495ce281bbf2d2
    components: [es8311]

# The base sits on the Atom's bottom header: I2C on G38/G39, I2S on G5-G8.
i2c:
  sda: GPIO38
  scl: GPIO39

pi4ioe5v6408:
  - id: base_io
    address: 0x43

i2s_audio:
  - id: i2s_audio_bus
    i2s_lrclk_pin: GPIO6
    i2s_bclk_pin: GPIO8

audio_dac:
  - platform: es8311
    id: es8311_dac
    bits_per_sample: 16bit
    sample_rate: 16000
    use_mclk: false
    mic_gain: 0DB  # overridden at boot by "Mic Digital Gain"

microphone:
  - platform: i2s_audio
    id: atom_mic
    i2s_audio_id: i2s_audio_bus
    i2s_din_pin: GPIO7
    adc_type: external
    sample_rate: 16000
    bits_per_sample: 16bit
    channel: left
    correct_dc_offset: true

speaker:
  - platform: i2s_audio
    id: atom_speaker
    i2s_audio_id: i2s_audio_bus
    i2s_dout_pin: GPIO5
    dac_type: external
    audio_dac: es8311_dac
    sample_rate: 16000
    bits_per_sample: 16bit
    channel: left
    buffer_duration: 60ms
    timeout: never
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

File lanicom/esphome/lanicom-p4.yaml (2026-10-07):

# lanicom on the Waveshare ESP32-P4-WIFI6-POE-ETH: serverless LAN intercom.
# No Mumble server, no Home Assistant needed (HA can adopt it, and can join as a peer).
#
# Hardware bring-up (pins, ES8311 mic quirks, gains) is the same as
# esp32-mumble/esphome/waveshare-esp32-p4-poe.yaml; see PROJECT_NOTES.md.
#
# First: cp secrets.example.yaml secrets.yaml and fill it in.
# First flash over USB-C:   esphome run lanicom-p4.yaml
# Then open http://<device>.local/ (user admin) and paste the network key (`lanicom keygen`),
# or bake it in with:       esphome -s network_key 'xxxxx-...' run lanicom-p4.yaml

substitutions:
  name: lanicom-p4
  friendly_name: Intercom
  # Buttons 1-4 on the carrier board (hardware/carrier), left to right: switches to GND on
  # GPIO23, 22, 21, 20; LED rings switched by a transistor from GPIO5, 32, 4, 33.
  # Pairing, LED patterns and the web page: docs/buttons.md.
  network_key: ""

esphome:
  name: ${name}
  friendly_name: ${friendly_name}
  name_add_mac_suffix: true
  min_version: "2026.7.0"
  on_boot:
    - priority: -100
      then:
        # ES8311 mic gain, straight to the codec (ESPHome's es8311 can't change it at runtime).
        - lambda: |-
            id(es8311_dac).write_byte(0x14, 0x10 | (uint8_t)(id(mic_pga).state / 3));
            id(es8311_dac).write_byte(0x16, (uint8_t)(id(mic_digital).state / 6));
        - speaker.volume_set:
            id: p4_speaker
            volume: !lambda 'return id(speaker_volume).state / 100.0f;'
        - lambda: |-
            id(intercom).set_ring_brightness(0, id(ring_1_brightness).state / 100.0f);
            id(intercom).set_ring_brightness(1, id(ring_2_brightness).state / 100.0f);
            id(intercom).set_ring_brightness(2, id(ring_3_brightness).state / 100.0f);
            id(intercom).set_ring_brightness(3, id(ring_4_brightness).state / 100.0f);
            id(intercom).set_night_brightness(id(night_brightness).state / 100.0f);
            id(intercom).set_night_hours((int) id(night_start).state, (int) id(night_end).state);

esp32:
  board: esp32-p4_r3  # rev3 silicon; pre-rev3 boards need `engineering_sample: true`
  flash_size: 16MB
  cpu_frequency: 360MHz
  framework:
    type: esp-idf  # ESPHome's native ESP-IDF toolchain (PlatformIO's can't link rev3 P4 builds)
    advanced:
      compiler_optimization: SIZE

psram:

ethernet:
  type: IP101
  mdc_pin: GPIO31
  mdio_pin: GPIO52
  power_pin: GPIO51
  clk:
    mode: CLK_EXT_IN
    pin: GPIO50
  phy_addr: 1

logger:
  hardware_uart: UART0  # USB-C is a CH343 UART bridge

# Management (HA API, web page, OTA) must be authenticated: whoever can change the network
# key or upload firmware can turn the box into a room bug. Copy secrets.example.yaml
# to secrets.yaml and fill it in.
#
# Optional Home Assistant link. reboot_timeout 0: without HA the device must not reboot.
api:
  reboot_timeout: 0s
  encryption:
    key: !secret api_encryption_key

ota:
  - platform: esphome
    password: !secret ota_password
  # Firmware upload on the web page: once the P4 is in its box, USB is out of reach.
  - platform: web_server

# Power-cycle the box 5 times within 10 s (e.g. toggle its PoE switch port) to clear everything
# set at runtime: links, brightness, and a key or name changed on the web page. The rings
# flash on each count.
# The clock for night brightness. Set your time zone; without a time server the rings
# simply stay at day brightness.
time:
  - platform: sntp
    id: sntp_clock
    timezone: Europe/Amsterdam

factory_reset:
  resets_required: 5
  max_delay: 10s
  on_increment:
    - lambda: 'id(intercom).identify(300);'

# Settings page for people without Home Assistant: http://<name>.local/
web_server:
  port: 80
  version: 3
  auth:
    type: digest
    username: admin
    password: !secret web_password

mdns:
  services:
    - service: "_lanicom"
      protocol: "_udp"
      port: 47100
      txt:
        v: "1"

external_components:
  - source:
      type: local
      path: components
  # Low-latency I2S: stock ESPHome queues ~50 ms on the speaker and reads the mic in 16 ms
  # blocks. Run `python tools/make_lowlatency_i2s.py` (with ESPHome's Python), then uncomment
  # to override the built-in i2s_audio (saves ~45 ms; check for audio glitches).
  # - source:
  #     type: local
  #     path: lowlatency/components
  #   components: [i2s_audio]

i2c:
  sda: GPIO7
  scl: GPIO8

i2s_audio:
  - id: i2s_audio_bus
    i2s_lrclk_pin: GPIO10
    i2s_bclk_pin: GPIO12
    i2s_mclk_pin: GPIO13

audio_dac:
  - platform: es8311
    id: es8311_dac
    bits_per_sample: 16bit
    sample_rate: 16000
    # Leave use_microphone off: in ESPHome's es8311 driver it selects a PDM digital mic.
    mic_gain: 0DB  # overridden at boot by "Mic Digital Gain"

microphone:
  - platform: i2s_audio
    id: p4_mic
    i2s_audio_id: i2s_audio_bus
    i2s_din_pin: GPIO11
    adc_type: external
    sample_rate: 16000
    bits_per_sample: 16bit
    channel: left
    correct_dc_offset: true
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

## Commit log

2026-10-03 esp32-mumble: ESP32-P4 support, voice sequence fix, VAD and mic improvements
    ESP32-P4 (Waveshare ESP32-P4-WIFI6-POE-ETH, rev3 silicon, Ethernet):
    - micro-opus: only enable the Xtensa LX7 paths on the ESP32-S3; register the
    vendored Opus as an IDF component (lib/micro-opus/CMakeLists.txt) for
    ESPHome's native esp-idf toolchain. PlatformIO's toolchain can't link rev3
    P4 builds (pioarduino 55.03.39 wants sections.rev3.ld.in, missing from its
    ESP-IDF 5.5.5).
    - Guard the Wi-Fi-only calls; use the Ethernet MAC for the default username.
    - New board config esphome/waveshare-esp32-p4-poe.yaml: Ethernet (IP101),
    ES8311 with the board's analog mic (use_microphone selects a PDM mic in
    ESPHom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
    [mumble_audio.cpp, mumble_component.cpp, mumble_component.h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]
2026-10-03 esp32-mumble: drop unused runtime Opus setters and encode timing
    The Opus bitrate/complexity sweep showed no audible or measurable gain, so
    the Home Assistant settings were removed and these hooks are unused.
    Claude-Session: https://claude.ai/code/session_01NmT8zZQWZTiXj38MZhU3tT
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2026-10-03 esp32-mumble: list the ESP32-P4 board in its README (as in the upstream PR branch)
    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
2026-10-03 PTT button on GPIO22 (button to GND, internal pull-up)
    Tested on the board: presses and holds start/stop TX, ~60 ms after the press.
    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
2026-10-06 lanicom: serverless LAN intercom (spec, C core, ESPHome, CLI, HA)
    A follow-up to the Mumble route that needs neither a Mumble server nor Home
    Assistant. Devices discover each other by authenticated broadcast and send
    Opus by encrypted unicast, with optional multicast. HA can join as a peer.
    - spec/: PROTOCOL.md, lanicom.proto and shared test vectors. Revised from
    the first draft: per-sender AEAD keys, epoch = boot counter || random,
    challenge/echo epoch verification against replays, a key_id in the
    header, jitter buffer ordered by ts, and a MONITOR capability for HA.
    - lanicom-core/: portable C99 engine (mbedTLS), host tests under
    ASan/UBSan, and an ESP-IDF component.
    - esphome/: la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
2026-10-06 lanicom: fix the speaker blocking the mic after playback
    Found on the board: after the speaker's hold ran out it restarted right
    away and kept the shared I2S bus, so every later mic start failed
    ("Driver failed to start"). ESPHome's speaker play() starts a stopped
    speaker, and two races let the audio task call it after stop():
    - the ready flag was set again while the bus was being released, because
    stop() is asynchronous and the speaker still reads as running;
    - the ready check and play() weren't atomic with the stop.
    Now a speaker mutex covers check+play and every stop, the ready flag is
    never set while releasing, and a safety net stops a speaker that runs
    while the bus isn't assigned to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
    [lanicom-p4.yaml, lanicom_component.cpp]
2026-10-06 voicetest: lanicom variant (laptop speech -> board mic -> lanicom -> Whisper)
    run-lanicom.sh plays a clip on this laptop, switches the board's Talk on over
    its encrypted API (lanicom_board.py, key from lanicom/esphome/secrets.yaml),
    records the stream with `lanicom record` and scores it with score.py.
    First run on the P4 (2026-10-06): Dutch test sentence, 0% WER, speech at
    about -24 dBFS.
2026-10-06 lanicom: click test and the first latency measurements on the P4
    tools/voicetest/clicktest.py plays clicks on the laptop next to the board,
    receives the board's lanicom stream, and times click -> packet on one
    PortAudio clock (laptop mic as a cross-check).
    Board sending half (mic DMA + frame + Opus + Wi-Fi):
    - stock ESPHome I2S: 35.6 / 33.8 ms median, ~8 ms spread
    - low-latency i2s_audio override: 22.4 / 27.0 ms median, ~2 ms spread
    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
2026-10-06 hardware: GPIO map, carrier spec, corrected plate DXF, enclosure prototype
    - GPIO map for the 2x20 header, from Waveshare's schematic: 10 free pins
    (GPIO20-23, 32, 33, 2-5). GPIO0/1 (32 kHz crystal), GPIO6 and GPIO54 (wired
    to the C6, 54 resets it) are not free, although they are on the header.
    - Carrier board specification (through-hole, BC547 LED drivers, JST-XH per
    button). The KiCad project still has to be made: no KiCad tools in this
    session.
    - plate/front-plate-arches.dxf: the plate with button holes 16 -> 19.4 mm
    and mounting holes 3.0 -> 3.3 mm.
    - enclosure/enclosure.py: parametric CadQuery shell + wall plate (hang on
    hooks, slide down, two screws from below), with a coll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
    [front-plate-arches.dxf]
2026-10-06 hardware: carrier board schematic (rev A)
    KiCad 10 project in hardware/carrier, made with the Konnect tools. The
    board plugs onto header P6 of the Waveshare ESP32-P4-WIFI6-POE-ETH and
    drives 4 illuminated buttons. All parts through-hole.
    - Buttons: GPIO22/20/21/23 through 1k, with 100nF to GND; the ESP32's
    own pull-up is used.
    - LED rings: GPIO32/33/4/5 drive BC547 low-side switches (1k base,
    10k pull-down) with R_LED fitted as 0R until the ring current is
    measured.
    - JST-XH button plugs: 1 = +5V, 2 = LED-, 3 = switch, 4 = GND.
    - GPIO2/3 are brought out to a spare header.
    Checks: ERC 0 errors and 0 warnings; no floating wires, unconnected pins,
    shorts or overlaps. KiCad's own netlist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
    [intercom-carrier-bom.csv, intercom-carrier.kicad_pcb, intercom-carrier.kicad_sch]
2026-10-06 hardware: carrier PCB layout (rev A) for the ESP32-P4-ETH
    Two 1x20 sockets for the P4's Pico-style header, four button/LED channels
    along the bottom edge, GND pours on both layers, four M3 holes.
    DRC: 0 errors, 0 unconnected. Gerbers, PDFs and BOM in carrier/export/.
    README and notes now describe the board actually used (P4-ETH, no WiFi).
    [intercom-carrier-bom.csv, intercom-carrier.kicad_pcb, intercom-carrier.kicad_sch]
2026-10-06 hardware: enclosure for the carrier + ESP32-P4-ETH stack
    The carrier sits on four M3 standoffs on the back wall, above the buttons,
    with the P4 (and its PoE module) facing the plate. The cable opening moved
    next to the RJ45 jack, the hooks moved above the carrier, and the back has
    recesses for the wall box screw heads. Adds an optional mic tube from the
    plate to the P4's mic. Collision check: none.
    Claude-Session: https://claude.ai/code/session_01CWRFtk6j7DsJxLJbKSRr78
2026-10-06 carrier: number buttons 1-4 left to right; PTT moves to GPIO23
    The channels were placed in the order their GPIOs leave the header (clean,
    crossing-free routing) but kept the old numbers, so the silkscreen read
    BTN4 BTN1 BTN3 BTN2. Renumbered the nets and parts instead of the copper:
    buttons 1-4 are GPIO23/22/21/20, LED rings GPIO5/32/4/33. PTT (button 1)
    is now GPIO23 in lanicom-p4.yaml. DRC 0 errors, 0 unconnected.
    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
    [intercom-carrier.kicad_pcb, intercom-carrier.kicad_sch]
2026-10-06 lanicom: design note for button pairing and LED patterns
    Link buttons on two devices by long-pressing both (5 s), no app needed.
    Draft protocol messages (PairOffer/Accept/Confirm, Unlink), per-button and
    whole-device LED patterns, and a later config page via ESPHome entities.
    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
2026-10-06 lanicom: buttons design: group calls, no zones, 1-button devices, one pairing gesture
    Decided: buttons are the only way to call; hold several to talk to all of
    them; devices may have a single button. Pairing proposal (open): only the
    initiating device needs an unlinked button; every other device blinks and
    a press accepts, adding a partner. LED patterns now use rhythms so a single
    ring can show every state.
    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
2026-10-06 lanicom: buttons design: one partner per button, per-button pairing, reset
    One button pairs with one button: hold an unlinked button 5 s, then another
    within 60 s. Linked buttons never pair, so long holds stay talks. Unpairing
    is a reset of the device's links (hold 30 s, or from the web page/HA); the
    links listed in Hello let partners drop stale links on their own. HA
    announcements reach every device.
    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
2026-10-06 lanicom: buttons design: reset via web page/HA only, HA addressing, web page contents
    No reset gesture on the buttons (kids). Unpair per button and factory reset
    on the web page or in HA; ESPHome's power-cycle count as a fallback. Key
    baked in, editable on the page. HA gets an ANNOUNCER caps bit and addresses
    any set of devices; zones are dropped from the devices.
    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
2026-10-06 lanicom: remove zones everywhere
    Buttons talk to their partners and Home Assistant picks devices itself, so
    nothing needs zones. Removed from the protocol (field numbers reserved),
    spec text, test vectors, C core, Python library and CLI, the HA integration
    (config flow, sensors, service text) and the ESPHome component and YAML.
    Targets are now 'all' or 'device:<id>'. To address several devices, HA's
    lanicom.announce takes a list ("Kitchen, Workshop"): one stream per
    device, each frame encoded once.
    C tests (ASan/UBSan), 35 Python tests incl. C interop, the HA announce
    test and an ESPHome compile pass. The HA config-flow test fails locally
    with the same socket-blocking error on the previous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
2026-10-07 hardware: enclosure in OpenSCAD instead of CadQuery
    Same design and dimensions, now one parametric intercom.scad plus render.sh
    (STLs, preview PNGs, collision check by intersection volume). Needs an
    OpenSCAD development snapshot (Manifold backend).
    Fixes found while porting:
    - The design frame (X right, Y up seen from the front, Z into the wall) is
    left-handed, so the old exports were mirror images of the box; the
    carrier's standoffs would not have matched the real board. All outputs
    are now mirrored once into the real frame.
    - The fixing-screw holes through the bottom and the insert holes in the
    wall plate's tabs were placed outside the parts and cut nothing.
    - The recesses for the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
    [intercom.scad]
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2026-10-07 enclosure: note that the P4's mic is top-port (hears towards the plate)
    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
    [intercom.scad]
2026-10-07 enclosure: aim the mic tube at the lid's sound hole
    The P4's MIC1 has its port near the end towards the USB-C, ~1 mm from the
    package centre. Collision check still clean.
    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
    [intercom.scad]
2026-10-07 enclosure: use the real plate; aim the mic tube through a grille opening
    OpenSCAD can't read the plate DXF's R12 polylines, so plate/dxf2scad.py
    converts it to front-plate-arches.scad (outline, 140 holes) and the model
    shows the actual arches grille instead of a dummy.
    With the real grille, 43% of the mic tube's bore landed on brass. The tube
    now starts behind an opening (1.3 mm clear around the bore) and slants ~7
    degrees to the mic. render.sh reports the bore coverage (now 0%).
    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
    [front-plate-arches.scad, intercom.scad]
2026-10-07 enclosure: round the plate recess's corners to follow the plate (R3 + 0.3 gap)
    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
    [intercom.scad]
2026-10-07 enclosure: round the shell's outer corners too (R5.7, even wall all round)
    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
    [intercom.scad]
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2026-10-07 enclosure: wire notch in the speaker chamber
    The chamber was closed on all sides, so the speaker's wires had no way
    out. A 4 x 3 mm notch where its wall towards the electronics meets the back
    wall; seal it after fitting to keep the chamber airtight.
    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
    [intercom.scad]
2026-10-07 docs(buttons): power-cycle reset settled, drop the open question
    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
2026-10-07 carrier: J6 silkscreen, one label per pin in the right order
    The old rotated label read GND at pin 1; pin 1 is GPIO2.
    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
    [intercom-carrier.kicad_pcb]
2026-10-07 carrier: silkscreen cleanup (hide hole names, upright labels, Q labels beside the transistors); regenerate exports
    DRC: 0 errors, 0 unconnected, no silkscreen warnings left.
    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
    [intercom-carrier.kicad_pcb]
2026-10-07 lanicom v1.1: button pairing, links and group talk in the protocol and core
    - spec: PairOffer/PairAccept/PairConfirm, Hello.links, CAP_ANNOUNCER (new field
    numbers stay clear of the ones the test vectors use as unknown fields)
    - core: lc_buttons (pairing state machine, self-healing links, talk set, ring
    states and levels); engine: device-set talks, links in Hello, control send
    - python: codec for the new messages, checked against official protobuf
    - ha: announce with CAP_ANNOUNCER, so boxes with buttons still play HA
    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
2026-10-07 esphome: four buttons with rings, pairing and group talk (lanicom v1.1)
    - buttons: option on the lanicom component (binary sensor + ring output each);
    links persist in flash, partners' and announcers' audio only
    - sender id derived from the MAC so a factory reset keeps it (partners then heal)
    - lanicom-p4.yaml: carrier pins, ring PWM, partner/unpair/identify/ring
    brightness entities, factory reset (button + 5 power cycles), web OTA
    - docs: buttons.md now describes what is built
    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
    [lanicom-p4.yaml, lanicom_component.cpp]
2026-10-07 lanicom: boot sweep, per-ring and night brightness, uptime
    - core: lc_led_boot_level (rings fade 1 -> n at start-up), lc_is_night
    - component: time_id, night_brightness/night_start/night_end, brightness per ring
    - lanicom-p4.yaml: SNTP clock, Button N brightness, Night brightness/from/until, uptime
    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
2026-10-07 esphome: AtomS3 Lite + Atomic Audio-3.5 Base config (one-button box)
    The base has no MCLK; the ES8311 runs 16 kHz from the bit clock only with 32-bit
    slots, so the I2S bus runs 32-bit both ways and lanicom now takes 32-bit mic
    samples (top 16 bits). Top button GPIO41 is the box's button; the RGB LED its ring.
    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
2026-10-07 lanicom: log when a button enters or leaves pairing mode
    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
2026-10-07 esphome: sensors publish only on change; Atom LED without gamma (10 % was off)
    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
2026-10-07 esphome: Atom without PSRAM crashed on the first Opus encode/decode
    micro-opus defaults to a 120 KB pseudostack per thread (PSRAM preferred); on the
    AtomS3 Lite the allocation fails and Opus writes through NULL. Only the audio task
    uses Opus, so use one 60 KB pseudostack in internal RAM there. Log free RAM once
    the codecs are up.
    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
    [lanicom-atoms3.yaml, lanicom_component.cpp]
2026-10-07 lanicom: max_streams option; reserve the Opus scratch area before the decoders
    On the AtomS3 (no PSRAM) only 31 KB of internal RAM was left in one piece after
    five codec instances, so the 60 KB pseudostack still failed. Now: test-encode right
    after creating the encoder (Opus allocates its scratch then), and the Atom uses two
    decoders (partner + an announcement). Boot log: encoder 31.6 KB, decoder 18.4 KB,
    43 KB free afterwards.
    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
    [lanicom-atoms3.yaml, lanicom_component.cpp]
2026-10-07 esphome: Atom last try: 10 ms frames, complexity 1, 24 KB audio stack, no captive portal
    The talk crash after the scratch fix jumped to a garbage PC during encode; give the
    audio task more stack and Opus less to do per frame. New option: audio_stack.
    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
    [lanicom-atoms3.yaml, lanicom_component.cpp]
2026-10-07 esphome: mark the AtomS3 Lite config as not working (no PSRAM)
    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
    [lanicom-atoms3.yaml]
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2026-10-07 esphome: Atomic Audio base works with M5Stack's es8311 fork; lanicom send is an announcer
    ESPHome's es8311 writes the clock pre-multiplier wrongly when the codec runs from
    the bit clock (no MCLK): the speaker only hisses. M5Stack's fork (pinned) encodes it
    and multiplies BCLK by 8, so plain 16-bit slots at 16 kHz work; the 32-bit-slot
    workaround is gone. Proven with a melody on the XIAO ESP32S3.
    lanicom send: CAP_ANNOUNCER, so boxes with buttons play it.
    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
    [lanicom-atoms3.yaml, lanicom-xiao.yaml]
2026-10-09 hardware: off switch on header pin 37 (3V3_EN), bodged onto the rev A carrier
    Pin 37 (EN) enables the P4's 3.3 V buck, so a switch to GND on J7.17/J7.18
    is a real power-off. Five flicks within 10 s still do a factory reset, on purpose.
2026-10-09 carrier rev B: off switch connector J8 on 3V3_EN
    J8 (JST-XH 2-pin, 1 = 3V3_EN / P4 pin 37, 2 = GND) with C6 100 nF across it,
    in the bottom-right corner next to the button JSTs. J5 moved 1.1 mm left to
    make room; its tracks are re-routed. 3V3_EN runs on B.Cu from J7.17.
    Mounting holes and J6 are unchanged, so the enclosure is too.
    ERC clean, DRC 0 errors / 0 unconnected. carrier/export/ is still rev A.
    [intercom-carrier.kicad_pcb, intercom-carrier.kicad_sch]
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
